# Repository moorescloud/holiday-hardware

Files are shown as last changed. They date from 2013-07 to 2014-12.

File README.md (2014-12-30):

MooresCloud Holiday Hardware
==============

The Holiday controller is an open source hardware design, originally inspired by the [Olimex OlinuXino] (https://www.olimex.com/Products/OLinuXino/iMX233/) - a Freescale iMX233 based embedded linux development board.

We used the OlinuXino iMX233 Maxi and Micro boards during development and testing of both the Light and Holiday, before designing our own custom PCB layout to suit the form factor and specific requirements.  The Holiday also incorporates an ATmega328 (running the "Arduino" environment) that communicates with the Linux environment for handling control during Linux boot-up and providing the tight timing requirements of sending data to the WS2812 LEDs.

These designs are in Altium Designer (v13) format, and the Altium files along with the BOM, PDF, and gerber outputs are now available under the [Creative Commons Attribution Share-Alike license] (http://creativecommons.org/licenses/by-sa/2.0/au/)

Controller r2a changes crystal Y2 from 16MHz to 20MHz
- this is the version that shipped in 2013/2014, with ECO001 applied

Controller r3 incorporated ECO001 changes and some other minor improvements noted in the schematics, and should be used with Globe r4 for signal integrity and EMC

The MooresGlobe used by Holiday went through several revision for prototyping and DFM review.

Globe r2b uses the WorldSemi WS2812 (6 pin 5050 footprint)
- this is the version that shipped in 2013/2014, with ECO002 applied

Globe r3 incorporated ECO002 and some other minor improvements

Globe r4 incorporated further improvements following discussions with WorldSemi and additional signal integrity and EMC measurements. This revision uses the newer WS2812B (4 pin 5050 footprint)

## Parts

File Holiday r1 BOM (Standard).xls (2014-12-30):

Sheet: Part List Report
 | Component list |  | Bill of Materials For Variant [Standard] of Project [Holiday r1.PrjPcb] (No PCB Document Selected)
 | Source Data From: |  | Holiday r1.PrjPcb |  |  | Report Date: | 7/05/2013 |  |  | 12:21:27 PM
 | Project: |  | Holiday r1.PrjPcb |  |  | Print Date: | 2013-05-17 |  |  | 21:22:57
 | Variant: |  | Standard
# | Designator | Description | Comment | 1.Manufacturer | 2.MfgNo | 3.Supplier | 4.CatNo | Quantity | 9.UnitCost | Total
1 | C1, C2, C3, C4, C5, C6, C8, C9, C10, C11, C13, C14, C16, C18, C19, C20, C39, C40, C45, C52, C53 | Capacitor | 22u | TDK | C1608X5R0J226M080AC | Digikey | 445-8028-1-ND | 21 | 0.0816 | $1.7136
2 | C7, C12, C15, C17, C22, C23, C24, C25, C26, C27, C28, C29, C31, C32, C34, C36, C38, C41, C44, C46, C47, C48, C56, C57 | Capacitor | 100n | Yageo | CC0603ZRY5V9BB104 | Digikey | 311-1343-2-ND | 24 | 0.0034 | $0.0816
3 | C30 | Capacitor | 10p | Murata | GRM1885C1H100JA01D | Digikey | 490-1403-1-ND | 1 | 0.008 | $0.0080
4 | C33, C35, C42, C43 | Capacitor | 18p | Murata | GRM1885C1H180JA01D | Digikey | 490-1409-2-ND | 4 | 0.008 | $0.0320
5 | C37 | Capacitor | 1u | Yageo | CC0603ZRY5V7BB105 | Digikey | 311-1372-2-ND | 1 | 0.0083 | $0.0083
6 | C50, C51 | Polarized Capacitor (Surface Mount) | 100uF, 10V, Tant | AVX | TPSD107K010R0100 | Digikey | 478-1777-2-ND | 2 | 0.33 | $0.6600
7 | D2, D3, D4, D5, D6 | Schottky Diode | BAT54 | Fairchild | BAT54 | Digikey | BAT54FSTR-ND | 5 | 0.027 | $0.1350
8 | J1 | microSD Socket Push/Pull | microSD | Molex | 473093751 | Digikey | WM3974TR-ND | 1 | 0.90 | $0.9000
9 | J6 | DC JACK | DC JACK | CUI Inc | PJ-002AH-SMT-TR | Digikey | CP-002AHPJTR-ND | 1 | 0.6554 | $0.6554
10 | J7 | USB A Female | USB A Female | Assmann | AU-Y1006-R | Digikey | AE9924-ND | 1 | 0.430 | $0.4300
11 | J8 | Connector | JST S3B-EH | JST | S3B-EH(LF)(SN) | Digikey | 455-1626-ND | 1 | 0.07216 | $0.0722
12 | L1 | Inductor | 22uH 1.5A | Taiyo Yuden | NR6045T220M | Digikey | 587-2082-1-ND | 1 | 0.12 | $0.1200
13 | L2 | Ferrite | 470nH | Abracon | AISC-0805-R47J-T | Digikey | 535-10509-1-ND | 1 | 0.10 | $0.1000
14 | L3 | Ferrite | 600R 1.5A | Laird | MI0805K601R-10 | DigiKey | 240-2390-2-ND | 1 | 0.025 | $0.0250
15 | L4, L6 | Ferrite | 750R 200mA | Laird | HZ0603B751R-10 | DigiKey | 240-2547-2-ND | 2 | 0.0165 | $0.0330
16 | L5, L7 | Ferrite | 120R 3.5A | Laird | HI0805O121R-10 | DigiKey | 240-2393-2-ND | 2 | 0.0234 | $0.0468
17 | Q1, Q2, Q3, Q4 | Dual N Channel MOSFET | BSS138PS | NXP | BSS138PS,115 | Digikey | 568-8393-2-ND | 4 | 0.07 | $0.2800
18 | R2, R12 | Resistor | 10k | Yageo | RC0603FR-0710KL | Digikey | 311-10.0KHRTR-ND | 2 | 0.0017 | $0.0034
19 | R4, R5, R6, R8 | Resistor | 1k | Yageo | RC0603FR-071KL | Digikey | 311-1.00KHRTR-ND | 4 | 0.0017 | $0.0068
20 | R7 | Resistor | 100k | Yageo | RC0603FR-07100KL | Digikey | 311-100KHRTR-ND | 1 | 0.0017 | $0.0017
21 | R9 | Resistor | 0R | Yageo | RC0603JR-070RL | Digikey | 311-0.0GRTR-ND | 1 | 0.00131 | $0.0013
22 | RP1 | Resistor Pack 4x0603 | 100k | Vishay Dale | CRA06S083100KJTA | Digikey | CRA6S8100KTR-ND | 1 | 0.009 | $0.0090
23 | RP2, RP3, RP4, RP5, RP6, RP7, RP8 | Resistor Pack 4x0603 | 10k | Vishay Dale | CRA06S08310K0JTA | Digikey | CRA6S810KTR-ND | 7 | 0.009 | $0.0630
24 | SW1, SW2, SW3 | Pushbutton SMT | TACTILE_SWITCH | TE Connectivity | FSM4JSMATR | Digikey | 450-1759-2-ND | 3 | 0.1543 | $0.4629
25 | U1 | Freescale i.MX233 128 pin LQFP package | MCIMX233DAG4B | Freescale | MCIMX233DAG4C | Digikey | MCIMX233DAG4C-ND | 1 | 4.880 | $4.8800
26 | U2 | SDRAM DDR400 66TSOP-II | H5DU5162ETR-E3C | Hynix | H5DU5162ETR-E3C |  |  | 1 | 2.240 | $2.2400
27 | U3 | ATMEGA328 - TQFP | ATMEGA328 | Atmel | ATMEGA328-AUR | Digikey | ATMEGA328-AURTR-ND | 1 | 1.608 | $1.6080
28 | U4, U5 | CMOS Logic Level Shifter | MC74VHC1GT50 | On Semi | M74VHC1GT50DTT1G | Digikey | M74VHC1GT50DTT1GOSTR-ND | 2 | 0.07 | $0.1400
29 | U6 | CAT24C64W EEPROM I2C | 8kB EEPROM | On Semi | CAT24C64WI-GT3 | Digikey | CAT24C64WI-GT3TR-ND | 1 | 0.148 | $0.1480
30 | Y1 | ABMM2 SMD Crystal | 24Mhz | Abracon | ABMM2-24.000MHZ-E2-T | Digikey | 535-9638-2-ND | 1 | 0.48 | $0.4800
31 | Y2 | ABMM2 SMD Crystal | 16MHz | Abracon | ABMM2-16.000MHZ-E2-T | Digikey | 535-9634-2-ND | 1 | 0.48 | $0.4800
32 | Z1 | SMBJ Unidirectional TVS | SMBJ TVS | Bourns | SMBJ6.0A | Digikey | SMBJ6.0ABTR-ND | 1 | 0.10 | $0.1000
33 | Z2, Z3, Z4 | Two-Line ESD-Protection in SOT23 | GSOT05C | Vishay Semi | GSOT05C-GS08 | Digikey | 751-1415-2-ND | 3 | 0.085 | $0.2550
Approved |  |  |  | Notes |  |  |  | 104 |  | $16.1800

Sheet: Project Information
Project Full Path | \\PIXEL\Users\Kean\My Documents\Kean Electronics\MooresCloud\PCB\Holiday r1\Holiday r1.PrjPcb
Project Filename | Holiday r1.PrjPcb
Variant Name | Standard
Data-Source Filename | Holiday r1.PrjPcb
Data-Source Full Path | \\PIXEL\Users\Kean\My Documents\Kean Electronics\MooresCloud\PCB\Holiday r1\Holiday r1.PrjPcb
Title | Bill of Materials For Variant [Standard] of Project [Holiday r1.PrjPcb] (No PCB Document Selected)
Total Quantity | 104
Report Time | 12:21:27 PM
Report Date | 7/05/2013
Report Date & Tine | 7/05/2013 12:21:27 PM
Output Name | Bill of Materials
Output Type | BOM_PartType
Output Generator Name | BOM
Output Generator Description | Bill of Materials

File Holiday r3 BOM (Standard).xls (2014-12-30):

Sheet: Part List Report
 | Component list |  | Bill of Materials For Variant [Standard] of Project [Holiday r3.PrjPcb] (No PCB Document Selected)
 | Source Data From: |  | Holiday r3.PrjPcb |  |  | Report Date: | 14/02/2014 |  |  | 4:12:48 PM
 | Project: |  | Holiday r3.PrjPcb |  |  | Print Date: | 2014-02-25 |  |  | 22:38:11
 | Variant: |  | Standard
# | Designator | Description | Comment | 1.Manufacturer | 2.MfgNo | 3.Supplier | 4.CatNo | Quantity | 9.UnitCost | Total
1 | C1, C2, C3, C4, C5, C6, C8, C9, C11, C13, C14, C16, C18, C19, C20, C39, C40 | Capacitor | 22u | TDK | C1608X5R0J226M080AC | Digikey | 445-8028-1-ND | 17 | 0.0816 | $1.3872
2 | C7, C12, C15, C17, C22, C23, C24, C25, C26, C27, C28, C29, C31, C32, C34, C36, C38, C41, C44, C46, C47, C48, C56, C57 | Capacitor | 100n | Yageo | CC0603ZRY5V9BB104 | Digikey | 311-1343-2-ND | 24 | 0.0034 | $0.0816
3 | C10, C45, C52, C53, C62, C63 | Capacitor | 22u 10V | TDK | C1608X5R1A226M080AC | Digikey | 445-9077-2-ND | 6 | 0.10500 | $0.6300
4 | C30 | Capacitor | 10p | Murata | GRM1885C1H100JA01D | Digikey | 490-1403-1-ND | 1 | 0.008 | $0.0080
5 | C33, C35, C42, C43 | Capacitor | 18p | Murata | GRM1885C1H180JA01D | Digikey | 490-1409-2-ND | 4 | 0.008 | $0.0320
6 | C37 | Capacitor | 1u | Yageo | CC0603ZRY5V7BB105 | Digikey | 311-1372-2-ND | 1 | 0.0083 | $0.0083
7 | C50, C51 | Polarized Capacitor (Surface Mount) | 100uF, 10V, Tant | AVX | TPSD107K010R0100 | Digikey | 478-1777-2-ND | 2 | 0.33 | $0.6600
8 | C54 | Capacitor | 470p | Yageo | CC0603JRNPO9BN471 | Digikey | 311-1520-2-ND | 1 | 0.00637 | $0.0064
9 | C61 | Capacitor | 1u | Taiyo Yuden | UMK212B7105KG-T | Digikey | 587-2910-2-ND | 1 | 0.03079 | $0.0308
10 | D2, D3, D4, D5 | Schottky Diode | BAT54 | Fairchild | BAT54 | Digikey | BAT54FSTR-ND | 4 | 0.027 | $0.1080
11 | J1 | microSD Socket Push/Pull | microSD | Molex | 473093751 | Digikey | WM3974TR-ND | 1 | 0.90 | $0.9000
12 | J6 | DC JACK | DC JACK | CUI Inc | PJ-002AH-SMT-TR | Digikey | CP-002AHPJTR-ND | 1 | 0.6554 | $0.6554
13 | J7 | USB A Female | USB A Female | Assmann | AU-Y1006-R | Digikey | AE9924-ND | 1 | 0.430 | $0.4300
14 | J8 | Connector | JST S3B-EH | JST | S3B-EH(LF)(SN) | Digikey | 455-1626-ND | 1 | 0.07216 | $0.0722
15 | L1 | Inductor | 22uH 1.5A | Taiyo Yuden | NR6045T220M | Digikey | 587-2082-1-ND | 1 | 0.12 | $0.1200
16 | L2 | Ferrite | 470nH | Abracon | AISC-0805-R47J-T | Digikey | 535-10509-1-ND | 1 | 0.10 | $0.1000
17 | L3, L8 | Ferrite | 600R 1.5A | Laird | MI0805K601R-10 | DigiKey | 240-2390-2-ND | 2 | 0.025 | $0.0500
18 | L4 | Ferrite | 750R 200mA | Laird | HZ0603B751R-10 | DigiKey | 240-2547-2-ND | 1 | 0.0165 | $0.0165
19 | L5, L7 | Ferrite | 120R 3.5A | Laird | HI0805O121R-10 | DigiKey | 240-2393-2-ND | 2 | 0.0234 | $0.0468
20 | Q1, Q2, Q3, Q4 | Dual N Channel MOSFET | BSS138PS | NXP | BSS138PS,115 | Digikey | 568-8393-2-ND | 4 | 0.07 | $0.2800
21 | R2, R12, R16 | Resistor | 10k | Yageo | RC0603FR-0710KL | Digikey | 311-10.0KHRTR-ND | 3 | 0.0017 | $0.0051
22 | R3 | Resistor | 120R | Yageo | RC0603FR-07120RL | Digikey | 311-120HRTR-ND | 1 | 0.0017 | $0.0017
23 | R4, R5, R6, R8, R13, R14 | Resistor | 1k | Yageo | RC0603FR-071KL | Digikey | 311-1.00KHRTR-ND | 6 | 0.0017 | $0.0102
24 | R7, R17 | Resistor | 100k | Yageo | RC0603FR-07100KL | Digikey | 311-100KHRTR-ND | 2 | 0.0017 | $0.0034
25 | R9 | Resistor | 0R | Yageo | RC0603JR-070RL | Digikey | 311-0.0GRTR-ND | 1 | 0.00131 | $0.0013
26 | R18 | Resistor | 75R | Yageo | RC0603FR-0775RL | DigiKey | 311-75.0HRTR-ND | 1 | 0.00171 | $0.0017
27 | RP1 | Resistor Pack 4x0603 | 100k | Vishay Dale | CRA06S083100KJTA | Digikey | CRA6S8100KTR-ND | 1 | 0.009 | $0.0090
28 | RP2, RP3, RP4, RP5, RP6 | Resistor Pack 4x0603 | 10k | Vishay Dale | CRA06S08310K0JTA | Digikey | CRA6S810KTR-ND | 5 | 0.009 | $0.0450
29 | RP7, RP8 | Resistor Pack 4x0603 | 4k7 | Vishay Dale | CRA06S0834K70JTA | Digikey | CRA6S84.7KTR-ND | 2 | 0.009 | $0.0180
30 | SW1, SW2, SW3 | Pushbutton SMT | TACTILE_SWITCH | TE Connectivity | FSM4JSMATR | Digikey | 450-1759-2-ND | 3 | 0.1543 | $0.4629
31 | U1 | Freescale i.MX233 128 pin LQFP package | MCIMX233DAG4B | Freescale | MCIMX233DAG4C | Digikey | MCIMX233DAG4C-ND | 1 | 4.880 | $4.8800
32 | U2 | SDRAM DDR400 66TSOP-II | H5DU5162ETR-E3C | Hynix | H5DU5162ETR-E3C |  |  | 1 | 2.240 | $2.2400
33 | U3 | ATMEGA328 - TQFP | ATMEGA328 | Atmel | ATMEGA328-AUR | Digikey | ATMEGA328-AURTR-ND | 1 | 1.608 | $1.6080
34 | U4, U5 | CMOS Logic Level Shifter | MC74VHC1GT50 | On Semi | M74VHC1GT50DTT1G | Digikey | M74VHC1GT50DTT1GOSTR-ND | 2 | 0.07 | $0.1400
35 | U6 | CAT24C64W EEPROM I2C | 8kB EEPROM | On Semi | CAT24C64WI-GT3 | Digikey | CAT24C64WI-GT3TR-ND | 1 | 0.148 | $0.1480
36 | Y1 | ABMM2 SMD Crystal | 24Mhz | Abracon | ABMM2-24.000MHZ-E2-T | Digikey | 535-9638-2-ND | 1 | 0.48 | $0.4800
37 | Y2 | ABMM2 SMD Crystal | 20MHz | Abracon | ABMM2-20.000MHZ-E2-T | Digikey | 535-9637-2-ND | 1 | 0.48 | $0.4800
38 | Z1 | SMBJ Unidirectional TVS | SMBJ TVS | Bourns | SMBJ6.0A | Digikey | SMBJ6.0ABTR-ND | 1 | 0.10 | $0.1000
39 | Z2, Z3, Z4 | Two-Line ESD-Protection in SOT23 | GSOT05C | Vishay Semi | GSOT05C-GS08 | Digikey | 751-1415-2-ND | 3 | 0.085 | $0.2550
Approved |  |  |  | Notes |  |  |  | 113 |  | $16.5124

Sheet: Project Information
Project Full Path | \\PIXEL\Users\Kean\My Documents\Kean Electronics\MooresCloud\PCB\Holiday r3\Holiday r3.PrjPcb
Project Filename | Holiday r3.PrjPcb
Variant Name | Standard
Data-Source Filename | Holiday r3.PrjPcb
Data-Source Full Path | \\PIXEL\Users\Kean\My Documents\Kean Electronics\MooresCloud\PCB\Holiday r3\Holiday r3.PrjPcb
Title | Bill of Materials For Variant [Standard] of Project [Holiday r3.PrjPcb] (No PCB Document Selected)
Total Quantity | 113
Report Time | 4:12:48 PM
Report Date | 14/02/2014
Report Date & Tine | 14/02/2014 4:12:48 PM
Output Name | Bill of Materials
Output Type | BOM_PartType
Output Generator Name | BOM
Output Generator Description | Bill of Materials

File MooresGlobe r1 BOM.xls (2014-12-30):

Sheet: Part List Report
 | Component list |  | Bill of Materials For Schematic Document [MooresGlobe r1.SchDoc]
 | Source Data From: |  | MooresGlobe r1.SchDoc |  |  | Report Date: | 3/05/2013 |  |  | 10:07:53 PM
 | Project: |  | MooresGlobe r1.PrjPcb |  |  | Print Date: | 2013-05-03 |  |  | 22:07:57
 | Variant: |  | None
# | Designator | Description | Footprint | 1.Manufacturer | 2.MfgNo | 3.Supplier | 4.CatNo | Quantity | 9.UnitCost | Total
1 | C1 | Capacitor Ceramic 100n 50V Y5V 0603 | ARA_0603 | Yageo | CC0603ZRY5V9BB104 | DigiKey | 311-1343-2-ND | 1 | 0.00206 | $0.0021
2 | LED1 | WorldSemi WS2812 Smart RGB LED | PLCC6-IPC | WorldSemi | WS2812 | Shenzhen Scott Electronics | sc-WS2811-5050 | 1 | 0.15 | $0.1500
3 | R1 | Resistor 100R 0.1W 5% 0603 | ARA_0603 | Yageo | RC0603JR-07100RL | DigiKey | 311-100GRTR-ND | 1 | 0.00092 | $0.0009
Approved |  |  |  | Notes |  |  |  | 3 |  | $0.1530

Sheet: Project Information
Project Full Path | \\PIXEL\Users\Kean\My Documents\Kean Electronics\MooresCloud\PCB\Globe r1\MooresGlobe r1.PrjPcb
Project Filename | MooresGlobe r1.PrjPcb
Variant Name | None
Data-Source Filename | MooresGlobe r1.SchDoc
Data-Source Full Path | \\PIXEL\Users\Kean\My Documents\Kean Electronics\MooresCloud\PCB\Globe r1\MooresGlobe r1.SchDoc
Title | Bill of Materials For Schematic Document [MooresGlobe r1.SchDoc]
Total Quantity | 3
Report Time | 10:07:53 PM
Report Date | 3/05/2013
Report Date & Tine | 3/05/2013 10:07:53 PM
Output Name | Bill of Materials
Output Type | BOM_PartType
Output Generator Name | BOM
Output Generator Description | Bill of Materials

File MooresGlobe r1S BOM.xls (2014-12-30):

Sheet: Part List Report
 | Component list |  | Bill of Materials For Schematic Document [MooresGlobe r1S.SchDoc]
 | Source Data From: |  | MooresGlobe r1S.SchDoc |  |  | Report Date: | 11/06/2013 |  |  | 8:02:30 PM
 | Project: |  | MooresGlobe r1S.PrjPcb |  |  | Print Date: | 2013-06-11 |  |  | 20:02:38
 | Variant: |  | None
# | Designator | Description | Comment | 1.Manufacturer | 2.MfgNo | 3.Supplier | 4.CatNo | Quantity | 9.UnitCost | Total
1 | C1 | Capacitor Ceramic 100n 50V Y5V 0603 | 100n | Yageo | CC0603ZRY5V9BB104 | DigiKey | 311-1343-2-ND | 1 | 0.00206 | $0.0021
2 | LED1 | WorldSemi WS2812 Smart RGB LED | WS2812 | WorldSemi | WS2812 | Shenzhen Scott Electronics | sc-WS2811-5050 | 1 | 0.15 | $0.1500
3 | R1 | Resistor 100R 0.1W 5% 0603 | 100R | Yageo | RC0603JR-07100RL | DigiKey | 311-100GRTR-ND | 1 | 0.00092 | $0.0009
Approved |  |  |  | Notes |  |  |  | 3 |  | $0.1530

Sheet: Project Information
Project Full Path | \\PIXEL\Users\Kean\My Documents\Kean Electronics\MooresCloud\PCB\Globe r1S\MooresGlobe r1S.PrjPcb
Project Filename | MooresGlobe r1S.PrjPcb
Variant Name | None
Data-Source Filename | MooresGlobe r1S.SchDoc
Data-Source Full Path | \\PIXEL\Users\Kean\My Documents\Kean Electronics\MooresCloud\PCB\Globe r1S\MooresGlobe r1S.SchDoc
Title | Bill of Materials For Schematic Document [MooresGlobe r1S.SchDoc]
Total Quantity | 3
Report Time | 8:02:30 PM
Report Date | 11/06/2013
Report Date & Tine | 11/06/2013 8:02:30 PM
Output Name | Bill of Materials
Output Type | BOM_PartType
Output Generator Name | BOM
Output Generator Description | Bill of Materials

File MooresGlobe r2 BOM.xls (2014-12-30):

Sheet: Part List Report
 | Component list |  | Bill of Materials For Schematic Document [MooresGlobe r2.SchDoc]
 | Source Data From: |  | MooresGlobe r2.SchDoc |  |  | Report Date: | 9/07/2013 |  |  | 12:20:01 PM
 | Project: |  | MooresGlobe r2.PrjPcb |  |  | Print Date: | 2013-07-09 |  |  | 12:20:08
 | Variant: |  | None
# | Designator | Description | Comment | 1.Manufacturer | 2.MfgNo | 3.Supplier | 4.CatNo | Quantity | 9.UnitCost | Total
1 | C1 | Capacitor Ceramic 100n 50V Y5V 0603 | 100n | Yageo | CC0603ZRY5V9BB104 | DigiKey | 311-1343-2-ND | 1 | 0.00206 | $0.0021
2 | LED1 | WorldSemi WS2812 Smart RGB LED | WS2812 | WorldSemi | WS2812 | Shenzhen Scott Electronics | sc-WS2811-5050 | 1 | 0.15 | $0.1500
3 | R1 | Resistor 100R 0.1W 5% 0603 | 100R | Yageo | RC0603JR-07100RL | DigiKey | 311-100GRTR-ND | 1 | 0.00092 | $0.0009
Approved |  |  |  | Notes |  |  |  | 3 |  | $0.1530

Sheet: Project Information
Project Full Path | \\PIXEL\Users\Kean\My Documents\Kean Electronics\MooresCloud\PCB\Globe r2\MooresGlobe r2.PrjPcb
Project Filename | MooresGlobe r2.PrjPcb
Variant Name | None
Data-Source Filename | MooresGlobe r2.SchDoc
Data-Source Full Path | \\PIXEL\Users\Kean\My Documents\Kean Electronics\MooresCloud\PCB\Globe r2\MooresGlobe r2.SchDoc
Title | Bill of Materials For Schematic Document [MooresGlobe r2.SchDoc]
Total Quantity | 3
Report Time | 12:20:01 PM
Report Date | 9/07/2013
Report Date & Tine | 9/07/2013 12:20:01 PM
Output Name | Bill of Materials
Output Type | BOM_PartType
Output Generator Name | BOM
Output Generator Description | Bill of Materials

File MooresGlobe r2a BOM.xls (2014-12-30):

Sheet: Part List Report
 | Component list |  | Bill of Materials For Schematic Document [MooresGlobe r2a.SchDoc]
 | Source Data From: |  | MooresGlobe r2a.SchDoc |  |  | Report Date: | 12/07/2013 |  |  | 3:11:09 PM
 | Project: |  | MooresGlobe r2a.PrjPcb |  |  | Print Date: | 2013-07-12 |  |  | 15:11:15
 | Variant: |  | None
# | Designator | Description | Comment | 1.Manufacturer | 2.MfgNo | 3.Supplier | 4.CatNo | Quantity | 9.UnitCost | Total
1 | C1 | Capacitor Ceramic 100n 50V Y5V 0603 | 100n | Yageo | CC0603ZRY5V9BB104 | DigiKey | 311-1343-2-ND | 1 | 0.00206 | $0.0021
2 | LED1 | WorldSemi WS2812 Smart RGB LED | WS2812 | WorldSemi | WS2812 | Shenzhen Scott Electronics | sc-WS2811-5050 | 1 | 0.15 | $0.1500
3 | R1 | Resistor 100R 0.1W 5% 0603 | 100R | Yageo | RC0603JR-07100RL | DigiKey | 311-100GRTR-ND | 1 | 0.00092 | $0.0009
Approved |  |  |  | Notes |  |  |  | 3 |  | $0.1530

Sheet: Project Information
Project Full Path | \\PIXEL\Users\Kean\My Documents\Kean Electronics\MooresCloud\PCB\Globe r2a\MooresGlobe r2a.PrjPcb
Project Filename | MooresGlobe r2a.PrjPcb
Variant Name | None
Data-Source Filename | MooresGlobe r2a.SchDoc
Data-Source Full Path | \\PIXEL\Users\Kean\My Documents\Kean Electronics\MooresCloud\PCB\Globe r2a\MooresGlobe r2a.SchDoc
Title | Bill of Materials For Schematic Document [MooresGlobe r2a.SchDoc]
Total Quantity | 3
Report Time | 3:11:09 PM
Report Date | 12/07/2013
Report Date & Tine | 12/07/2013 3:11:09 PM
Output Name | Bill of Materials
Output Type | BOM_PartType
Output Generator Name | BOM
Output Generator Description | Bill of Materials

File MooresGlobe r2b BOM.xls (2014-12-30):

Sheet: Part List Report
 | Component list |  | Bill of Materials For Schematic Document [MooresGlobe r2b.SchDoc]
 | Source Data From: |  | MooresGlobe r2b.SchDoc |  |  | Report Date: | 20/08/2013 |  |  | 11:01:06 AM
 | Project: |  | MooresGlobe r2b.PrjPcb |  |  | Print Date: | 2013-08-20 |  |  | 11:01:14
 | Variant: |  | None
# | Designator | Description | Comment | 1.Manufacturer | 2.MfgNo | 3.Supplier | 4.CatNo | Quantity | 9.UnitCost | Total
1 | C1 | Capacitor Ceramic 100n 50V Y5V 0603 | 100n | Yageo | CC0603ZRY5V9BB104 | DigiKey | 311-1343-2-ND | 1 | 0.00206 | $0.0021
2 | LED1 | WorldSemi WS2812 Smart RGB LED | WS2812 | WorldSemi | WS2812 | Shenzhen Worldsemi Technology | WS2812 | 1 | 0.15 | $0.1500
3 | R1 | Resistor 100R 0.1W 5% 0603 | 100R | Yageo | RC0603JR-07100RL | DigiKey | 311-100GRTR-ND | 1 | 0.00092 | $0.0009
Approved |  |  |  | Notes |  |  |  | 3 |  | $0.1530

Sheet: Project Information
Project Full Path | \\PIXEL\Users\Kean\My Documents\Kean Electronics\MooresCloud\PCB\Globe r2b\MooresGlobe r2b.PrjPcb
Project Filename | MooresGlobe r2b.PrjPcb
Variant Name | None
Data-Source Filename | MooresGlobe r2b.SchDoc
Data-Source Full Path | \\PIXEL\Users\Kean\My Documents\Kean Electronics\MooresCloud\PCB\Globe r2b\MooresGlobe r2b.SchDoc
Title | Bill of Materials For Schematic Document [MooresGlobe r2b.SchDoc]
Total Quantity | 3
Report Time | 11:01:06 AM
Report Date | 20/08/2013
Report Date & Tine | 20/08/2013 11:01:06 AM
Output Name | Bill of Materials
Output Type | BOM_PartType
Output Generator Name | BOM
Output Generator Description | Bill of Materials

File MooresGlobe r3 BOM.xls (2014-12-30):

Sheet: Part List Report
 | Component list |  | Bill of Materials For Schematic Document [MooresGlobe r3.SchDoc]
 | Source Data From: |  | MooresGlobe r3.SchDoc |  |  | Report Date: | 12/11/2013 |  |  | 3:54:06 PM
 | Project: |  | MooresGlobe r3.PrjPcb |  |  | Print Date: | 2013-11-12 |  |  | 15:54:08
 | Variant: |  | None
# | Designator | Description | Comment | 1.Manufacturer | 2.MfgNo | 3.Supplier | 4.CatNo | Quantity | 9.UnitCost | Total
1 | C1 | Capacitor Ceramic 100n 50V Y5V 0603 | 100n | Yageo | CC0603ZRY5V9BB104 | DigiKey | 311-1343-2-ND | 1 | 0.00206 | $0.0021
2 | C2 | Capacitor Ceramic 470p 50V NPO 0603 | 470p | Yageo | CC0603JRNPO9BN471 | DigiKey | 311-1520-2-ND | 1 | 0.00526 | $0.0053
3 | LED1 | WorldSemi WS2812 Smart RGB LED | WS2812 | WorldSemi | WS2812 | Shenzhen Worldsemi Technology | WS2812 | 1 | 0.15 | $0.1500
4 | R1 | Resistor 100R 0.1W 5% 0603 | 100R | Yageo | RC0603JR-07100RL | DigiKey | 311-100GRTR-ND | 1 | 0.00092 | $0.0009
5 | R2 | Resistor 100R 0.1W 5% 0603 | 0R | Yageo | RC0603JR-070RL | DigiKey | 311-0.0GRTR-ND | 1 | 0.00092 | $0.0009
Approved |  |  |  | Notes |  |  |  | 5 |  | $0.1592

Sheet: Project Information
Project Full Path | \\PIXEL\Users\Kean\My Documents\Kean Electronics\MooresCloud\PCB\Globe r3\MooresGlobe r3.PrjPcb
Project Filename | MooresGlobe r3.PrjPcb
Variant Name | None
Data-Source Filename | MooresGlobe r3.SchDoc
Data-Source Full Path | \\PIXEL\Users\Kean\My Documents\Kean Electronics\MooresCloud\PCB\Globe r3\MooresGlobe r3.SchDoc
Title | Bill of Materials For Schematic Document [MooresGlobe r3.SchDoc]
Total Quantity | 5
Report Time | 3:54:06 PM
Report Date | 12/11/2013
Report Date & Tine | 12/11/2013 3:54:06 PM
Output Name | Bill of Materials
Output Type | BOM_PartType
Output Generator Name | BOM
Output Generator Description | Bill of Materials

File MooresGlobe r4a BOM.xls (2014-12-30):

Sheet: Part List Report
 | Component list |  | Bill of Materials For Schematic Document [MooresGlobe r4a.SchDoc]
 | Source Data From: |  | MooresGlobe r4a.SchDoc |  |  | Report Date: | 21/02/2014 |  |  | 11:58:54 AM
 | Project: |  | MooresGlobe r4a.PrjPcb |  |  | Print Date: | 2014-02-21 |  |  | 12:09:30
 | Variant: |  | None
# | Designator | Description | Comment | 1.Manufacturer | 2.MfgNo | 3.Supplier | 4.CatNo | Quantity | 9.UnitCost | Total
1 | C1 | Capacitor Ceramic 100n 50V Y5V 0603 | 100n | Yageo | CC0603ZRY5V9BB104 | DigiKey | 311-1343-2-ND | 1 |  | $0.0000
2 | C2 | Capacitor Ceramic 220p 50V NPO 0603 | 220p | Samsung | CL10C221JB8NNNC | DigiKey | 1276-1048-2-ND | 1 |  | $0.0000
3 | LED1 | WorldSemi WS2812B Smart RGB LED | WS2812B | WorldSemi | WS2812B | WorldSemi | WS2812B | 1 |  | $0.0000
4 | R1 | Resistor 330R 0.1W 5% 0603 | 330R | Yageo | RC0603JR-07330RL | DigiKey | 311-330GRTR-ND | 1 |  | $0.0000
5 | R2 | Resistor 75R 0.1W 5% 0603 | 75R | Yageo | RC0603JR-0775RL | DigiKey | 311-75GRTR-ND | 1 |  | $0.0000
Approved |  |  |  | Notes |  |  |  | 5 |  | $0.0000

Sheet: Project Information
Project Full Path | \\PIXEL\Users\Kean\My Documents\Kean Electronics\MooresCloud\PCB\Globe r4a\MooresGlobe r4a.PrjPcb
Project Filename | MooresGlobe r4a.PrjPcb
Variant Name | None
Data-Source Filename | MooresGlobe r4a.SchDoc
Data-Source Full Path | \\PIXEL\Users\Kean\My Documents\Kean Electronics\MooresCloud\PCB\Globe r4a\MooresGlobe r4a.SchDoc
Title | Bill of Materials For Schematic Document [MooresGlobe r4a.SchDoc]
Total Quantity | 5
Report Time | 11:58:54 AM
Report Date | 21/02/2014
Report Date & Tine | 21/02/2014 11:58:54 AM
Output Name | Bill of Materials
Output Type | BOM_PartType
Output Generator Name | BOM
Output Generator Description | Bill of Materials

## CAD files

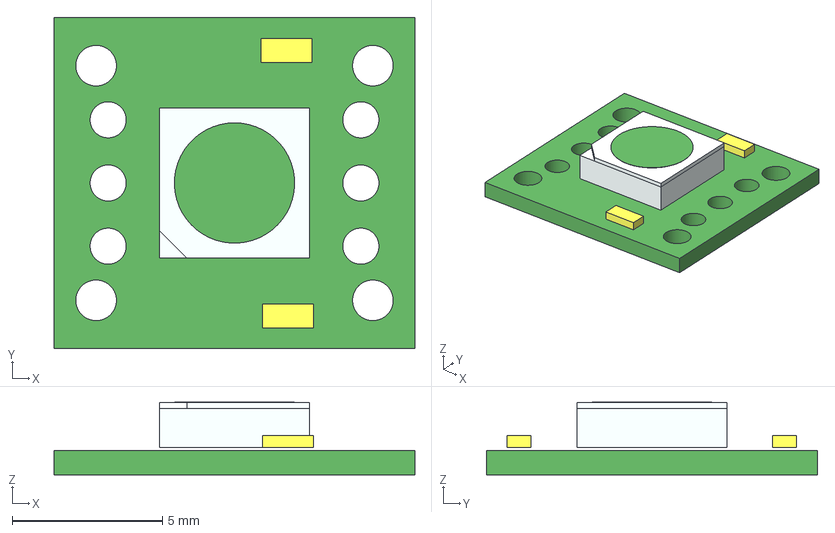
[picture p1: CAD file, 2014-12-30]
MooresGlobe r2a.step
12.0 x 11.0 x 2.41 mm
Board
Extruded x 4

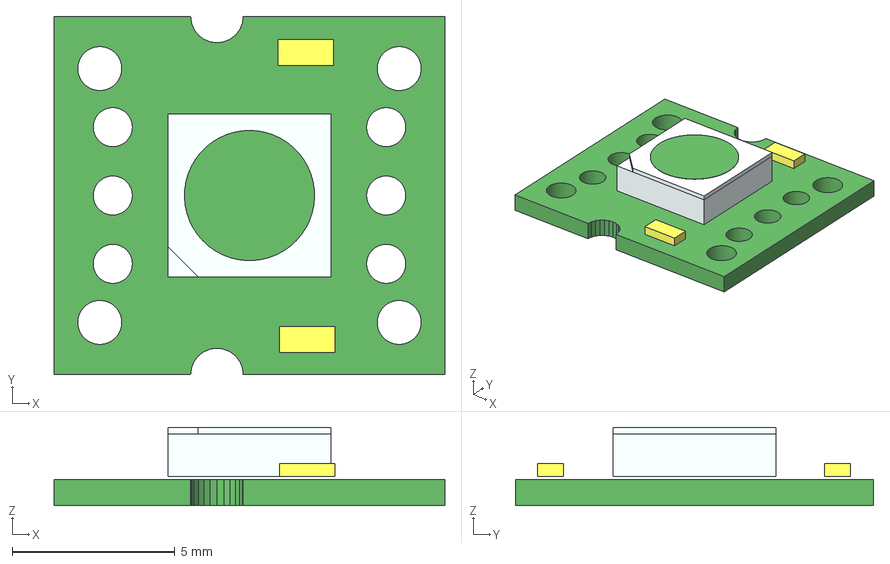
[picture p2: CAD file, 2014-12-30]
MooresGlobe r2.step
12.0 x 11.0 x 2.41 mm
Board
Extruded x 4

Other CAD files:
MooresGlobe r1.step

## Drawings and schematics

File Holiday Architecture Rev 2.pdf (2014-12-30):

# MOORESCLOUD HOLIDAY HARDWARE ARCHITECTURE

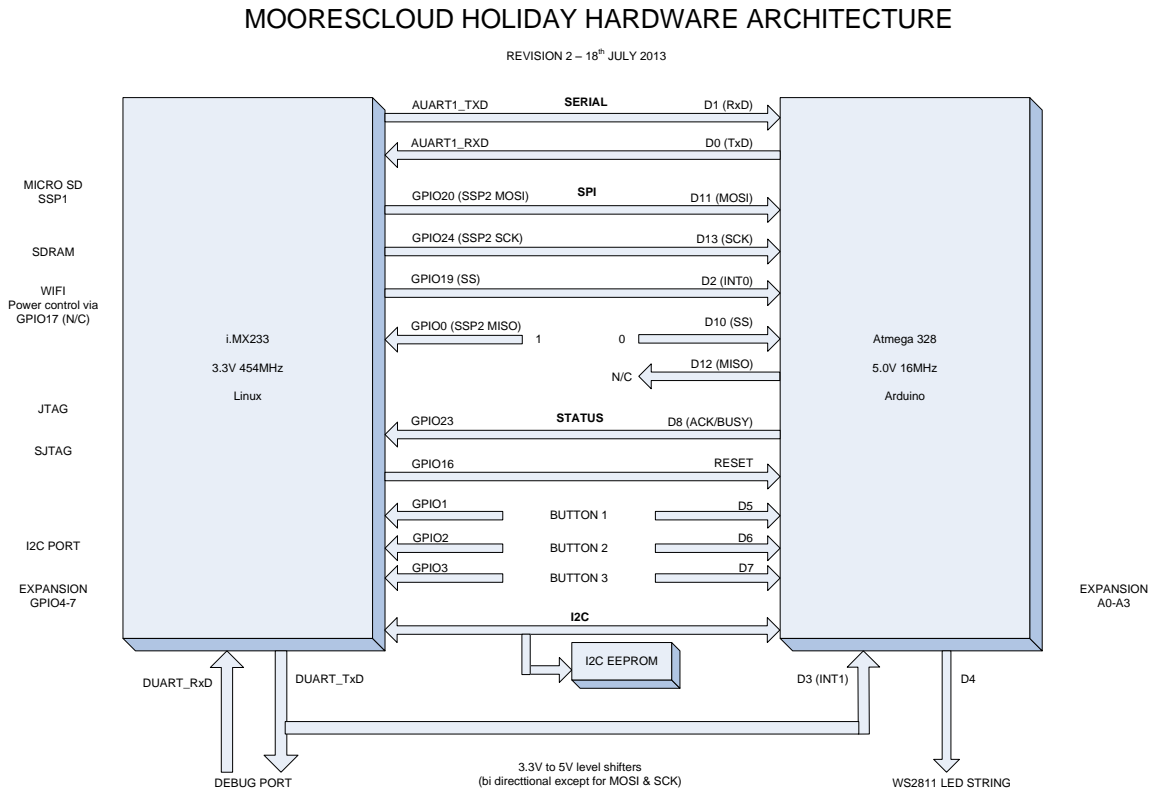
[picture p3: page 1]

3.3V to 5V level shifters (bi directtional except for MOSI & SCK)

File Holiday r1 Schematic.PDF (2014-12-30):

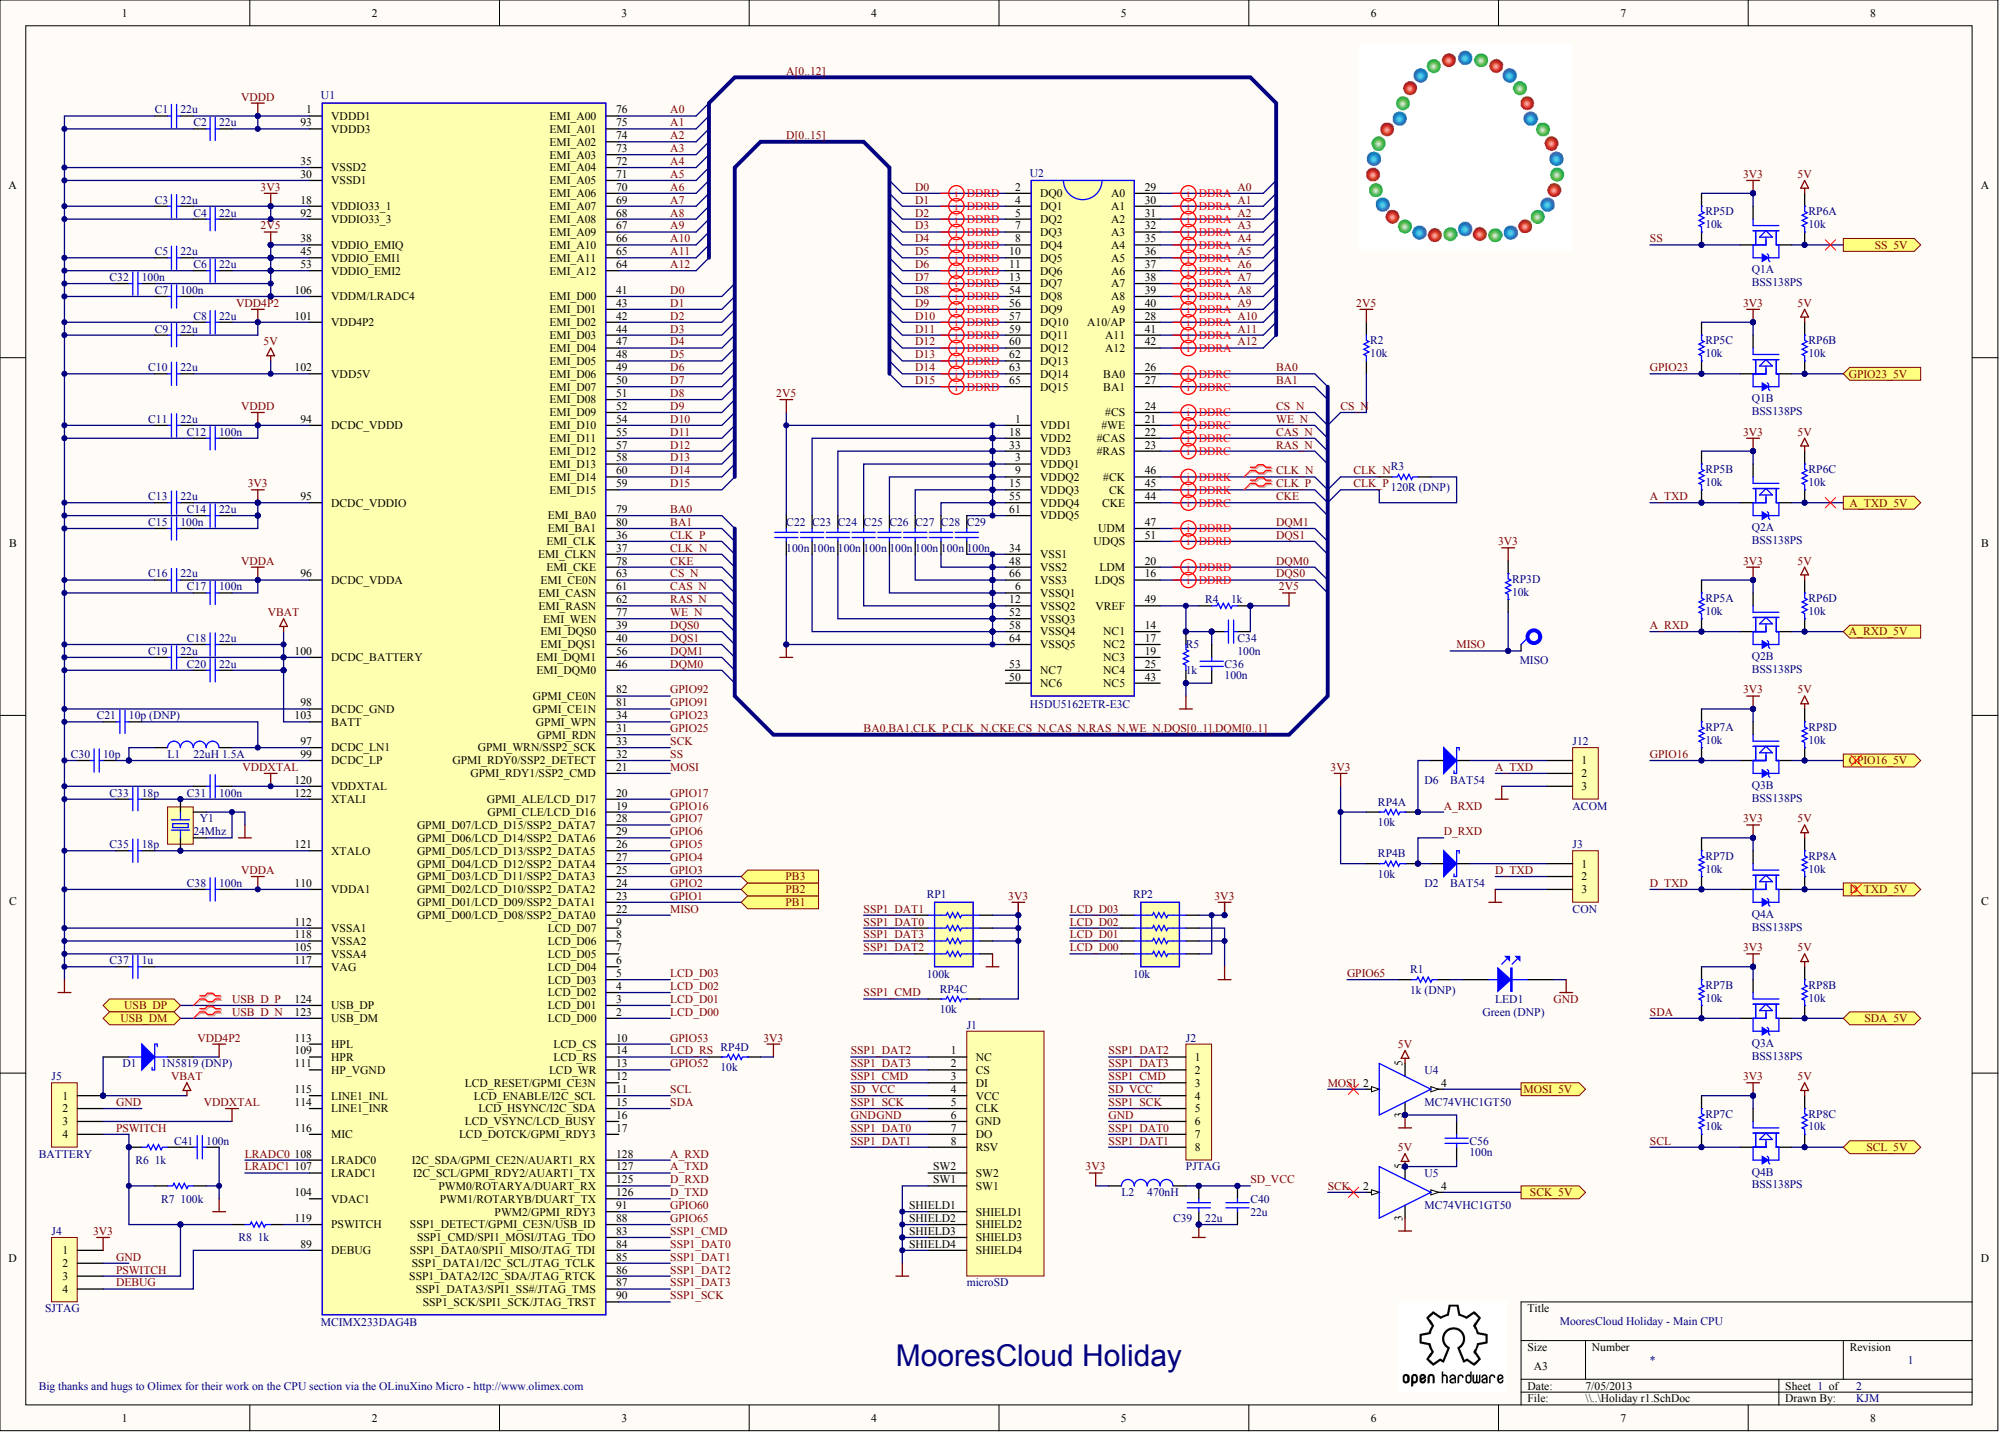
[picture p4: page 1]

i DDRD i DDRD i DDRD i DDRD i DDRD i DDRD i DDRD i DDRD i DDRD i DDRD i DDRD i DDRD i DDRD i DDRD i DDRD

i DDRA i DDRK i DDRK
i DDRA i DDRA i DDRA i DDRA i DDRA i DDRA i DDRA i DDRA i DDRA i DDRA i DDRA i DDRA i DDRD i DDRD i DDRD i DDRD

i DDRC i DDRC i DDRC i DDRC i DDRC i DDRC i DDRC

VDDQ3 15

VSS2 48
VSS3 66

VSSQ2 12

VSSQ4 58

SHIELD1
SHIELD2
SHIELD3

MooresCloud Holiday - Main CPU

Big thanks and hugs to Olimex for their work on the CPU section via the OLinuXino Micro - http://w

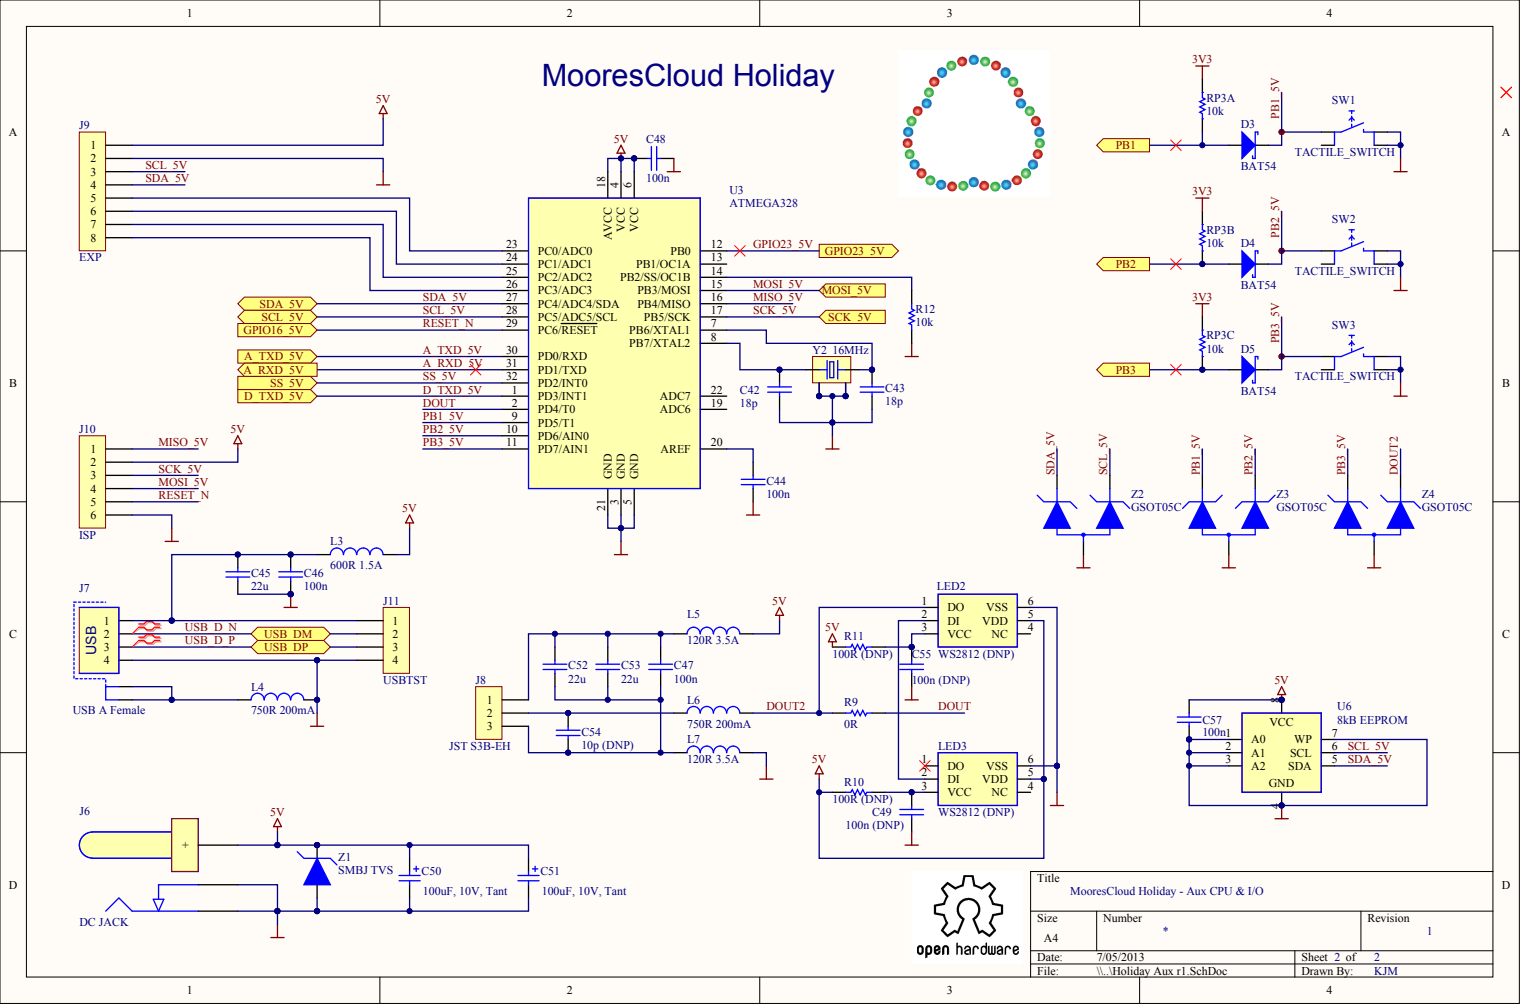
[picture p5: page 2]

PC1/ADC1 24
PC2/ADC2 25
PC3/ADC3 26 | MOSI_5V

PD0/RXD 30 | 8

Y2 16MHz

MooresCloud Holiday - Aux CPU & I/O

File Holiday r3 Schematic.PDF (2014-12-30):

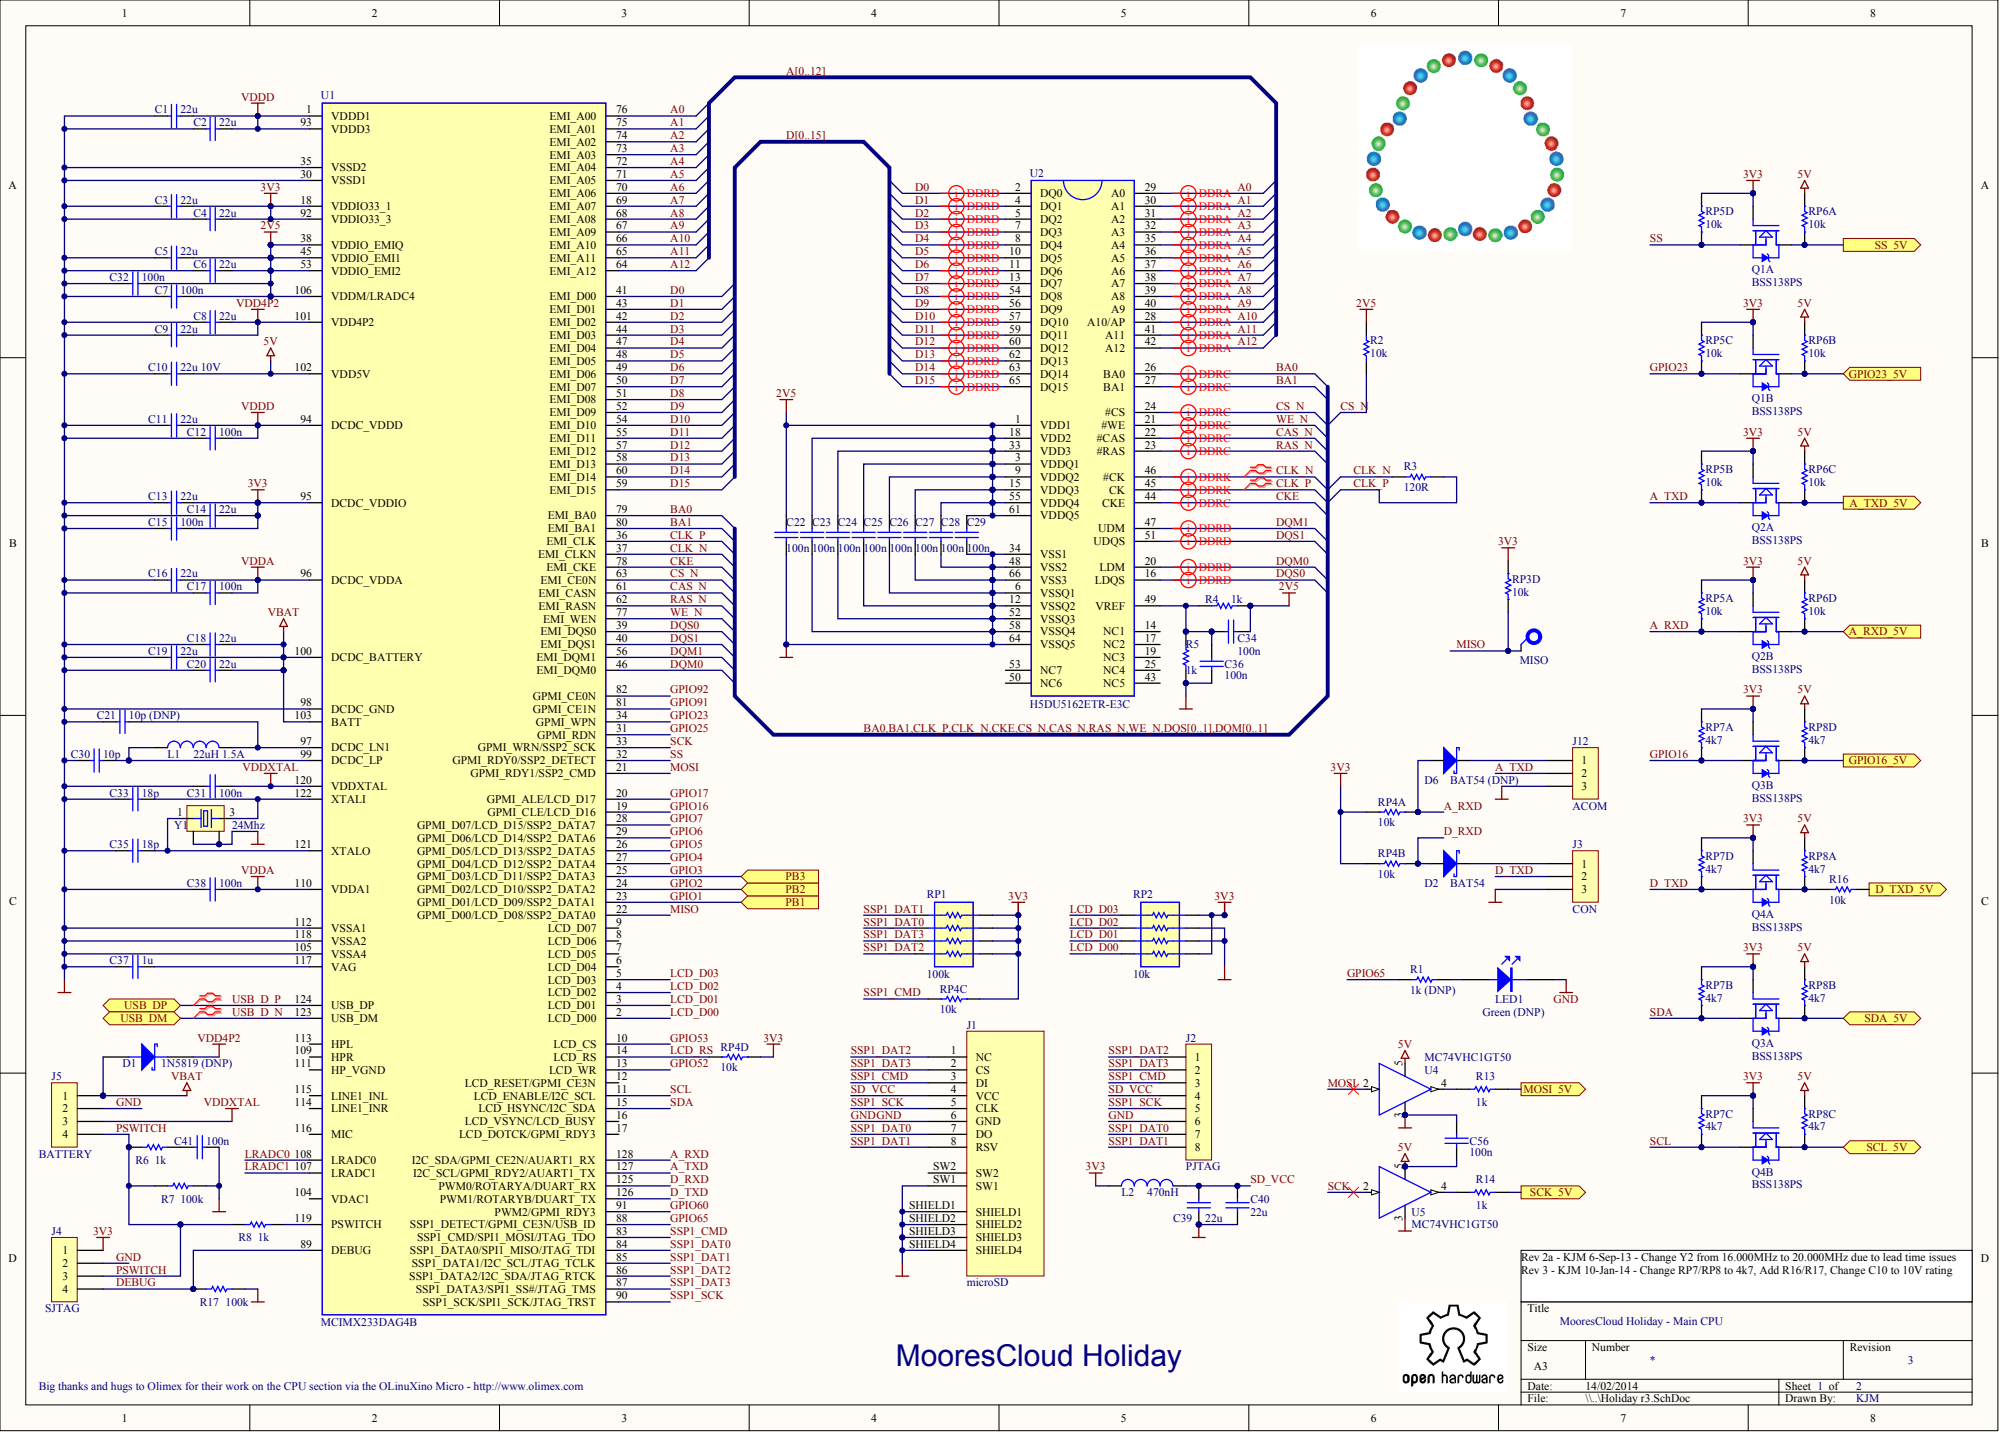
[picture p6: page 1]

i DDRD i DDRD i DDRD i DDRD i DDRD i DDRD i DDRD i DDRD i DDRD i DDRD i DDRD i DDRD i DDRD i DDRD i DDRD

i DDRA i DDRK i DDRK
i DDRA i DDRA i DDRA i DDRA i DDRA i DDRA i DDRA i DDRA i DDRA i DDRA i DDRA i DDRA i DDRD i DDRD i DDRD i DDRD

i DDRC i DDRC i DDRC i DDRC i DDRC i DDRC i DDRC

VDDQ3 15 | CLK_P
VDDQ4 55

VSS2 48
VSS3 66

VSSQ2 12

VSSQ4 58

SHIELD1
SHIELD2
SHIELD3

Rev 2a - KJM 6-Sep-13 - Change Y2 from 16.000MHz to 20.000MHz due to lead time issues
Rev 3 - KJM 10-Jan-14 - Change RP7/RP8 to 4k7, Add R16/R17, Change C10 to 10V rating

MooresCloud Holiday - Main CPU

Big thanks and hugs to Olimex for their work on the CPU section via the OLinuXino Micro - http://w

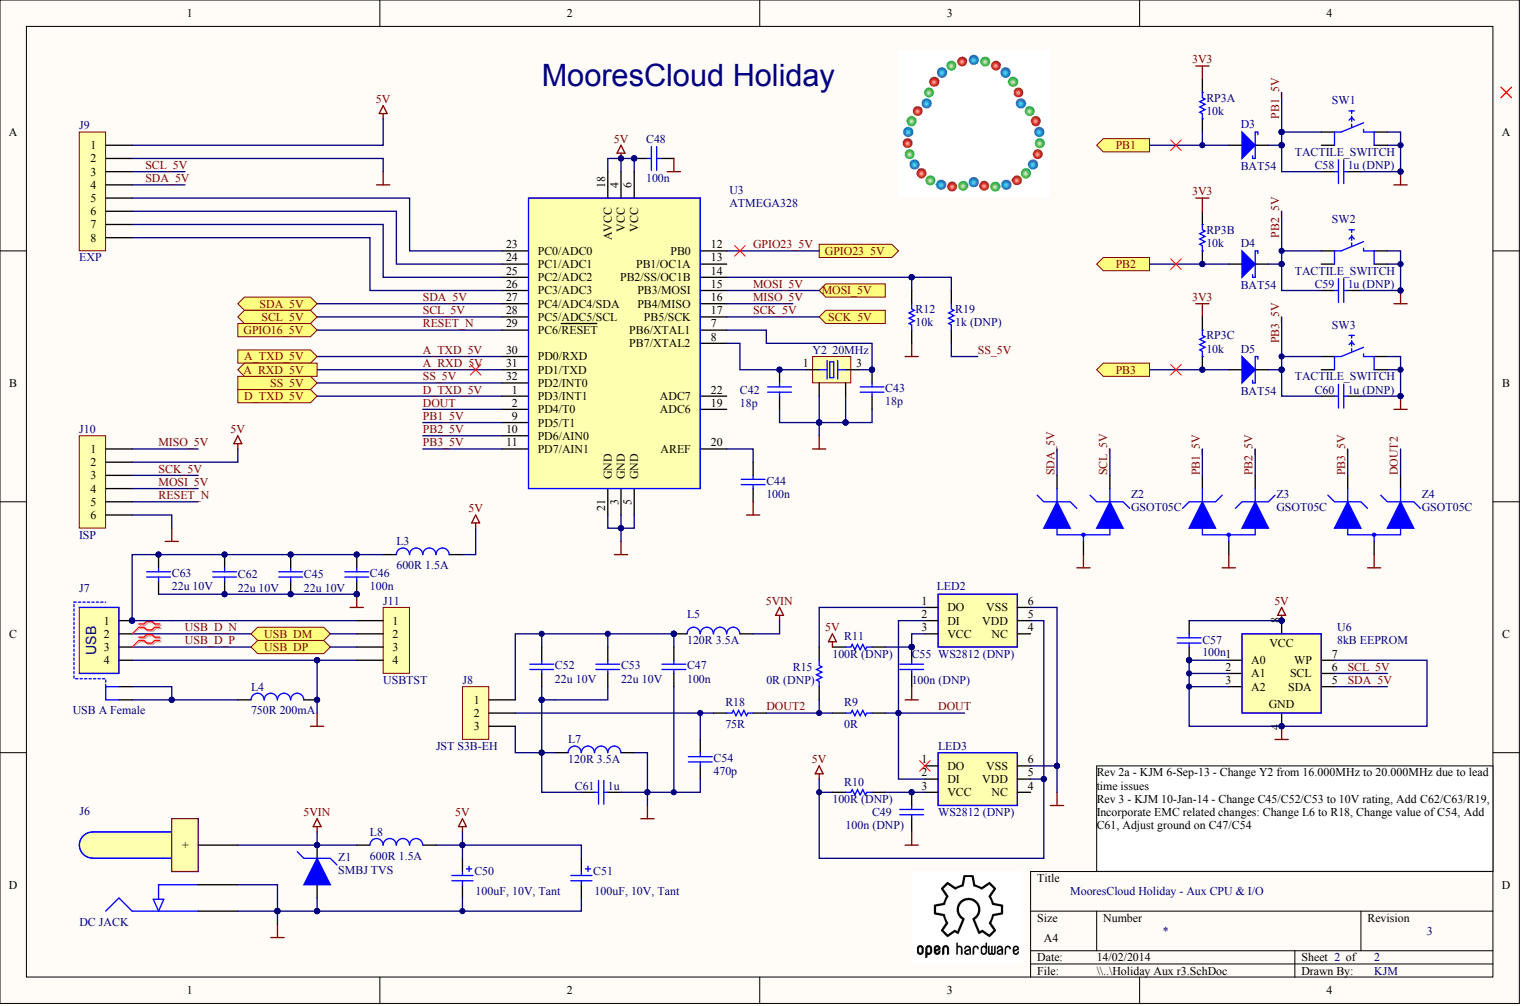
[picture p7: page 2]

PC2/ADC2 25
PC3/ADC3 26 | MOSI_5V

PD0/RXD 30 | 8

Y2 20MHz 1

Rev 2a - KJM 6-Sep-13 - Change Y2 from 16.000MHz to 20.000MHz due to lead
time issues
Rev 3 - KJM 10-Jan-14 - Change C45/C52/C53 to 10V rating, Add C62/C63/R19, Incorporate EMC related changes: Change L6 to R18, Change value of C54, Add

MooresCloud Holiday - Aux CPU & I/O

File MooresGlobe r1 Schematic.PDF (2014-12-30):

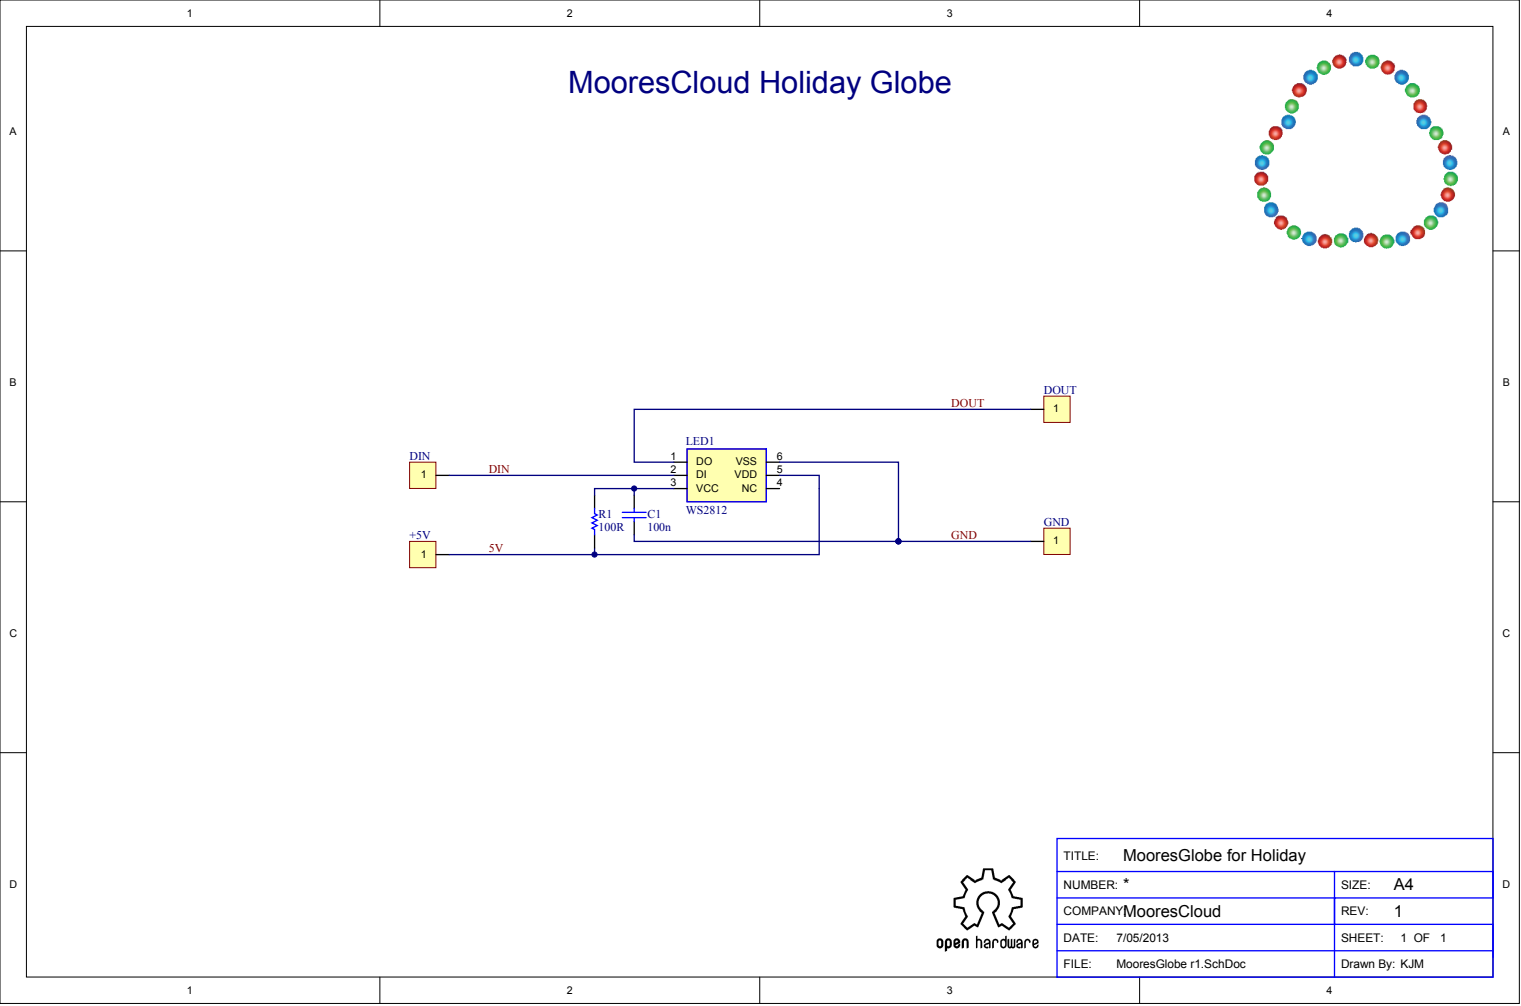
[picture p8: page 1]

NUMBE R : * | SIZE : A4
COMPAN YMooresCloud : | REV : 1

DATE : 7/05/20 1 3 | SHEE T : 1 O F 1

FILE : MooresGlobe r1.SchDoc | Drawn By : KJ M

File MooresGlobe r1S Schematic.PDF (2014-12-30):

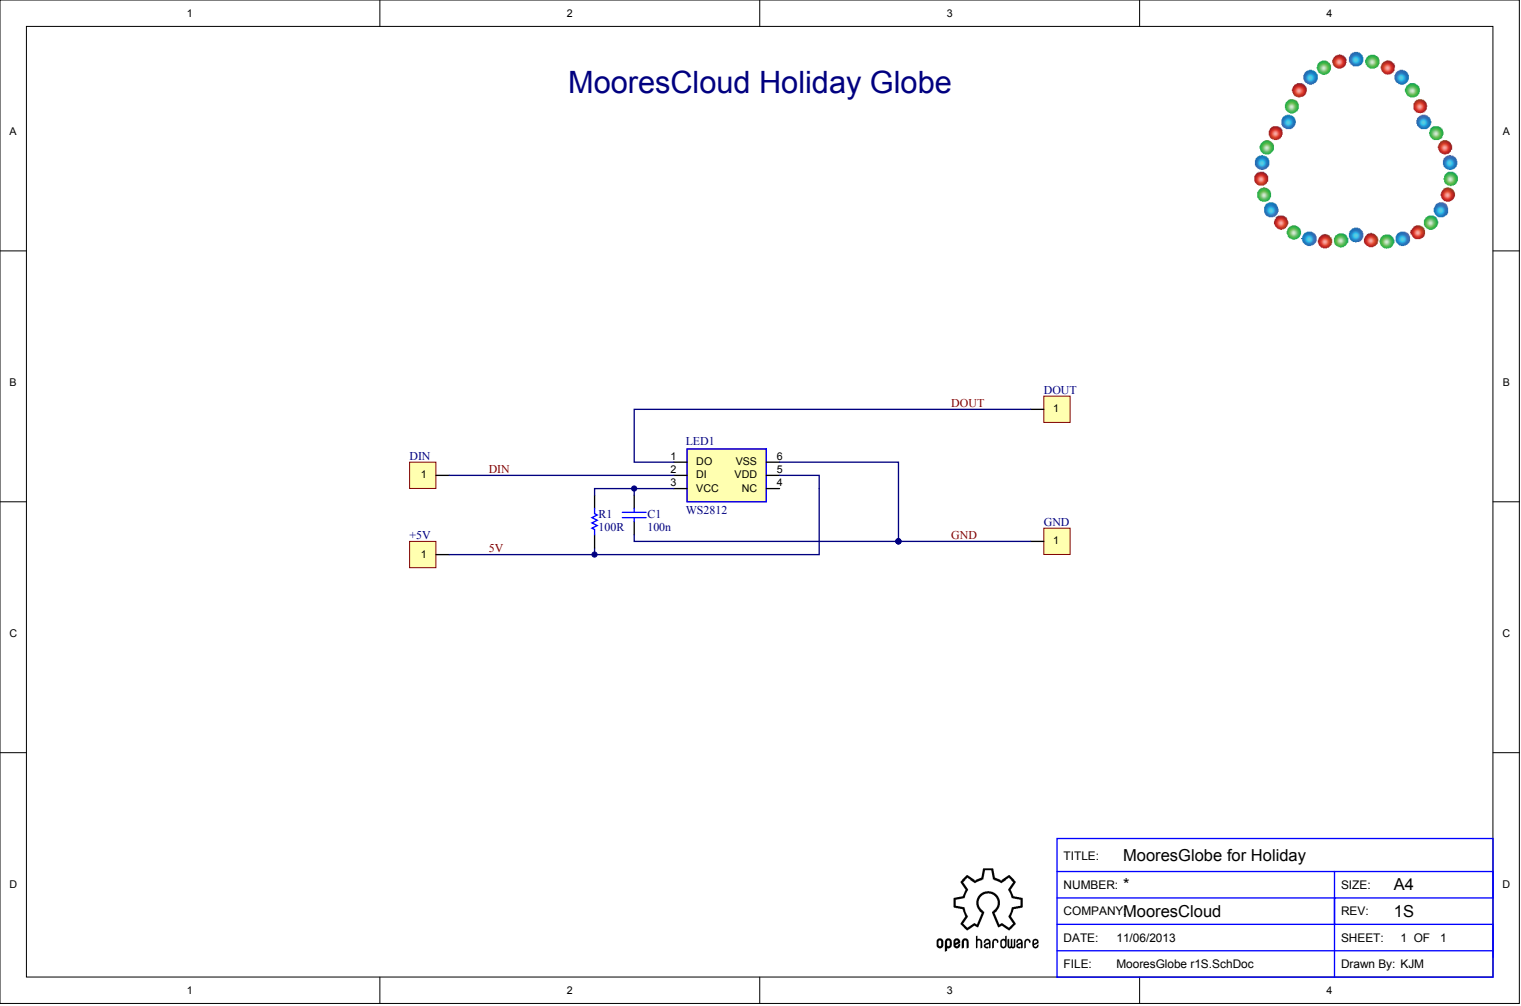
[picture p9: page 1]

NUMBE R : * | SIZE : A4
COMPAN YMooresCloud : | REV : 1S

DATE : 11/06/20 1 3 | SHEE T : 1 O F 1

FILE : MooresGlobe r1S.SchDoc | Drawn By : KJ M

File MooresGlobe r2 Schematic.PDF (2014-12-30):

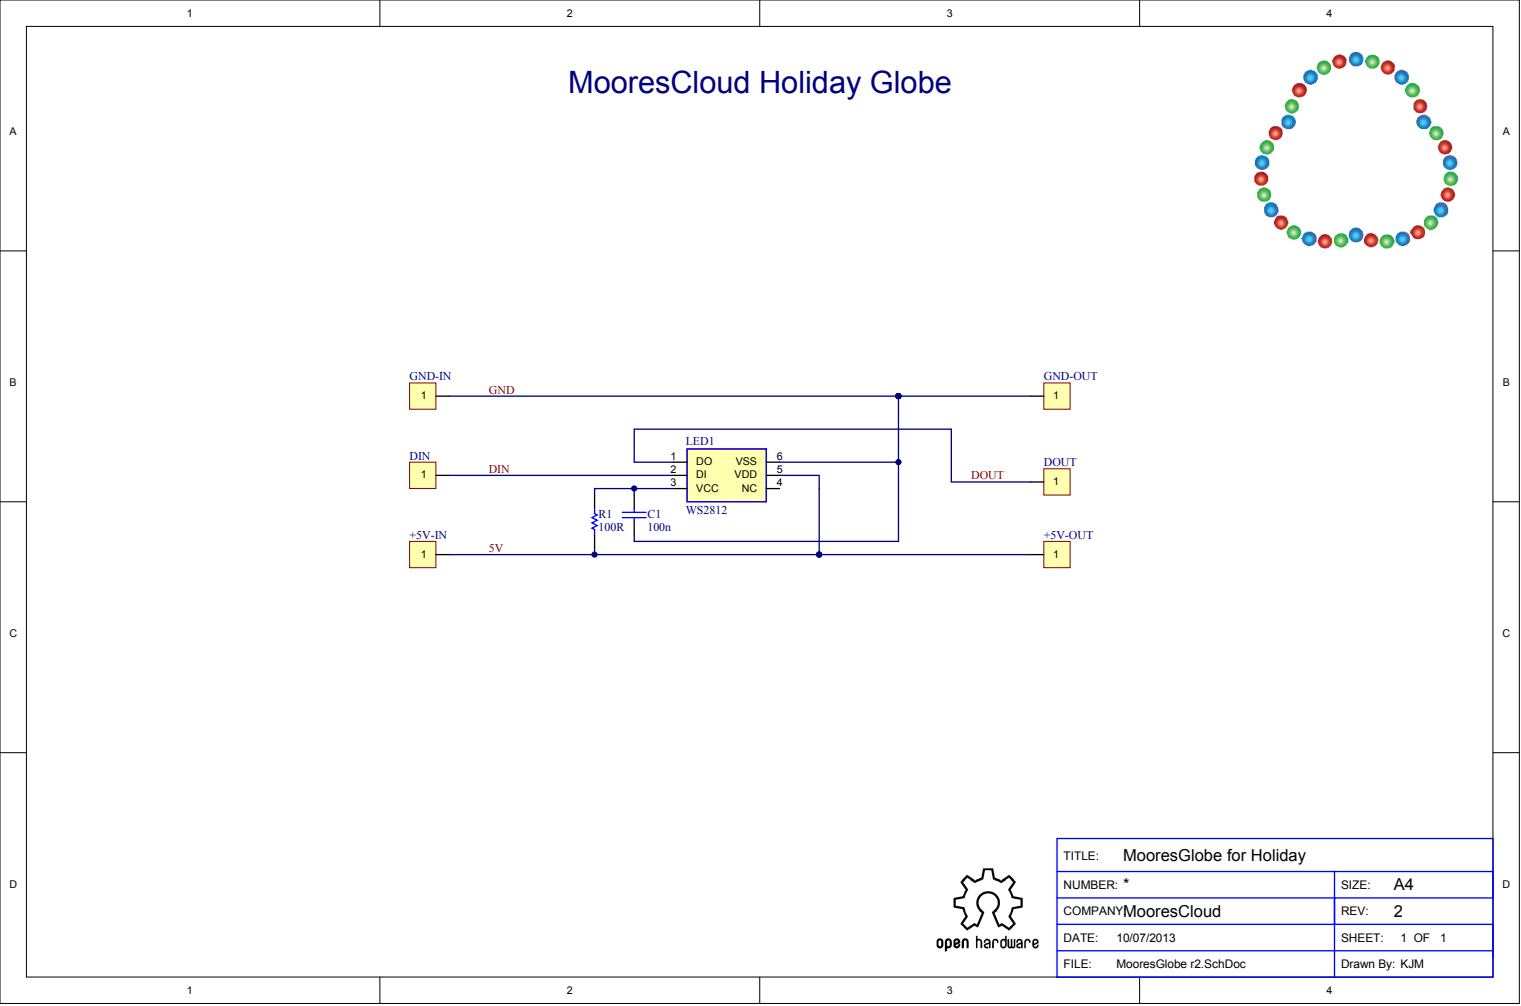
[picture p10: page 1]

NUMBE R : * | SIZE : A4
COMPAN YMooresCloud : | REV : 2

DATE : 10/07/20 1 3 | SHEE T : 1 O F 1

FILE : MooresGlobe r2.SchDoc | Drawn By : KJ M

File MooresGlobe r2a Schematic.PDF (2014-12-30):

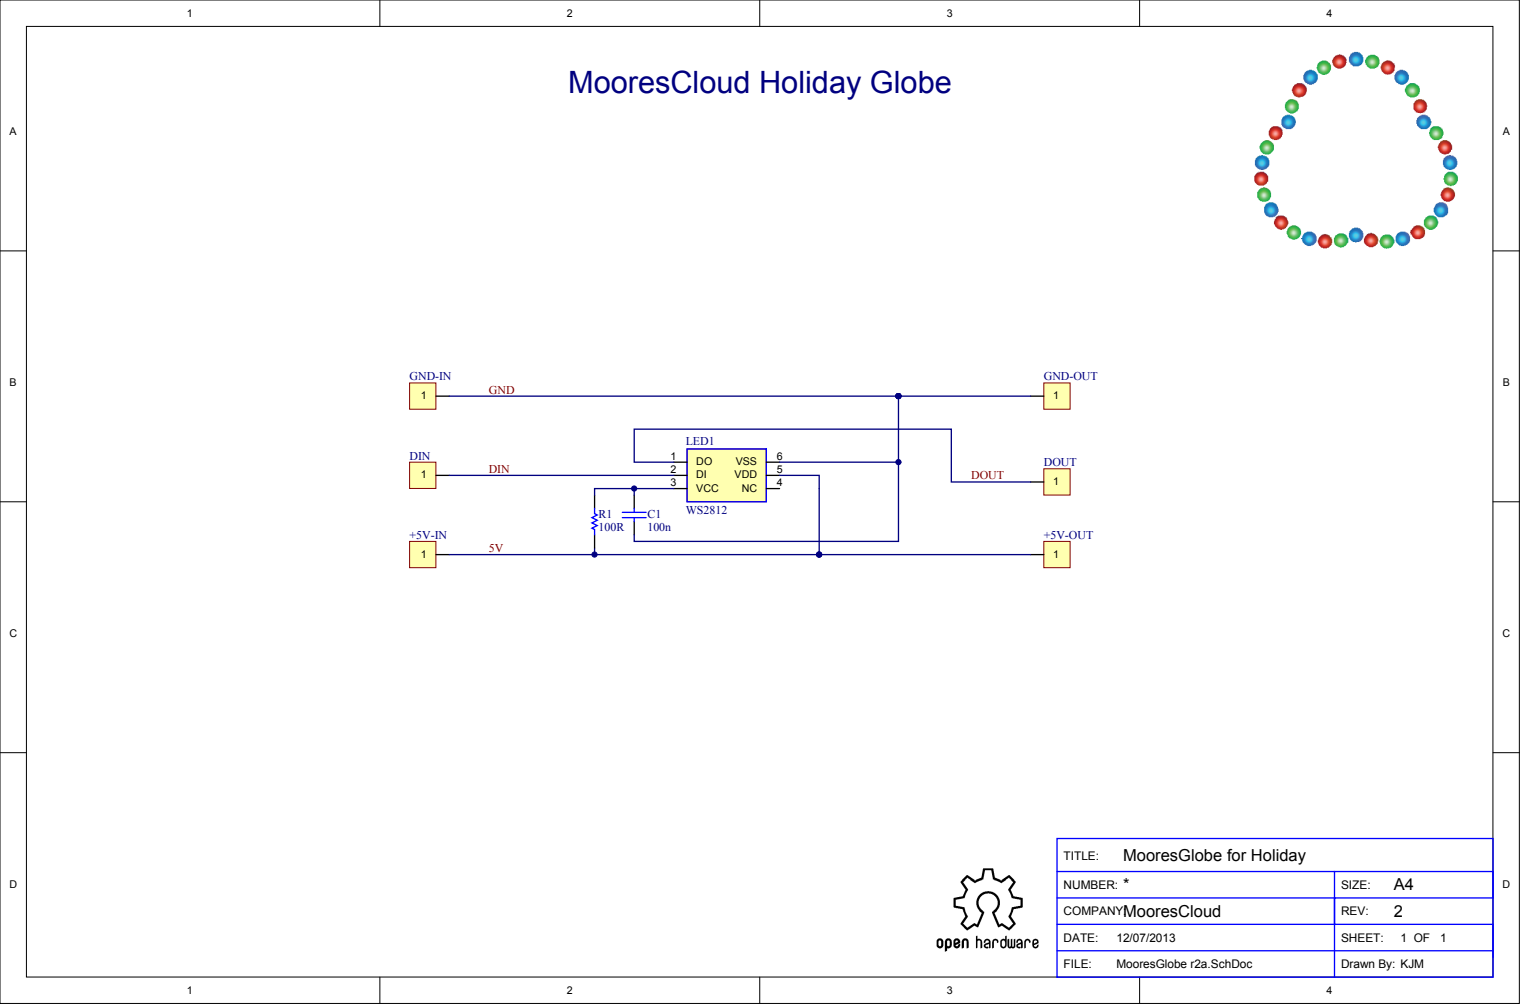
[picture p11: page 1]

NUMBE R : * | SIZE : A4
COMPAN YMooresCloud : | REV : 2

DATE : 12/07/20 1 3 | SHEE T : 1 O F 1

FILE : MooresGlobe r2a.SchDoc | Drawn By : KJ M

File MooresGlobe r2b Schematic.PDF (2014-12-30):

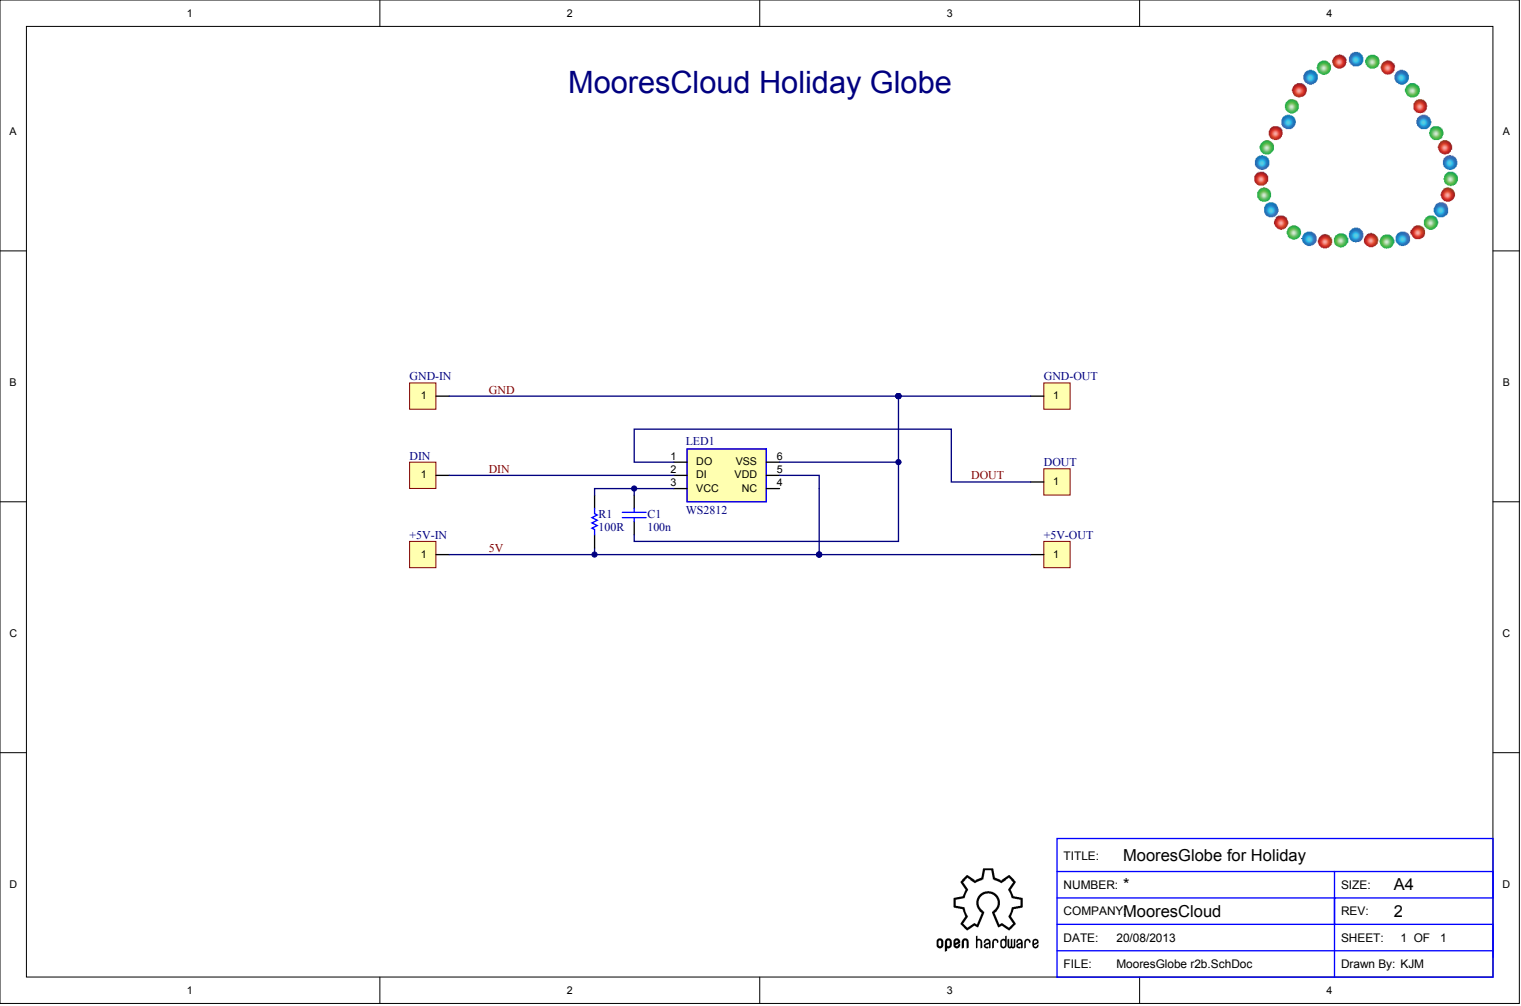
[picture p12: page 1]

NUMBE R : * | SIZE : A4
COMPAN YMooresCloud : | REV : 2

DATE : 20/08/20 1 3 | SHEE T : 1 O F 1

FILE : MooresGlobe r2b.SchDoc | Drawn By : KJ M

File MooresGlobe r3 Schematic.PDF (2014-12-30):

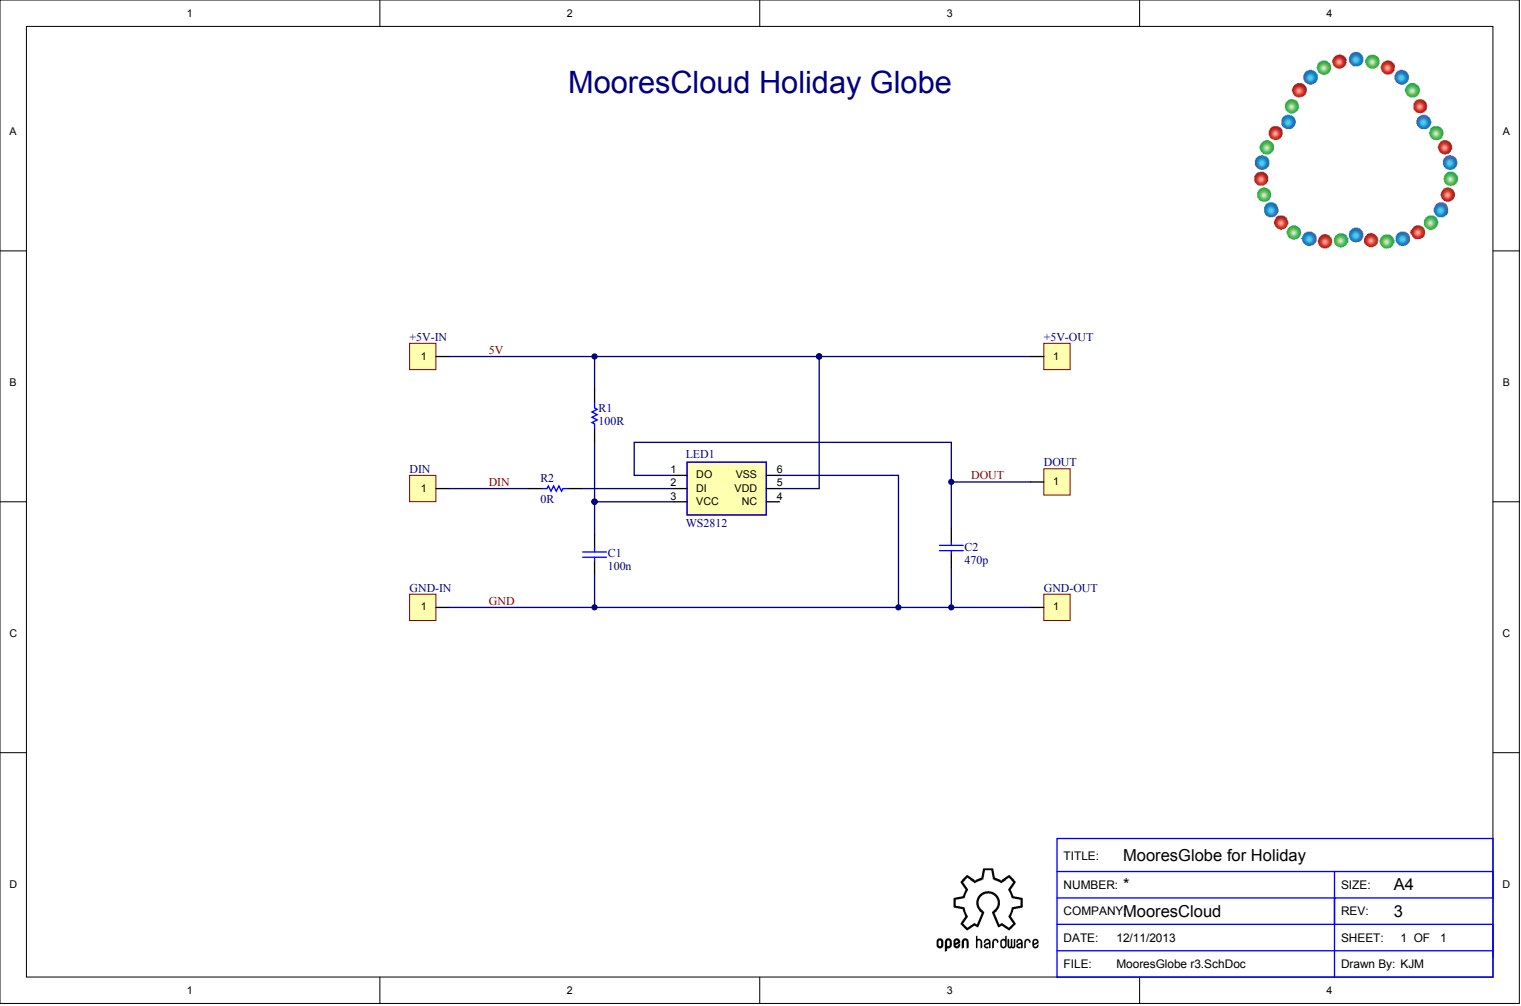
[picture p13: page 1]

NUMBE R : * | SIZE : A4
COMPAN YMooresCloud : | REV : 3

DATE : 12/11/20 1 3 | SHEE T : 1 O F 1

FILE : MooresGlobe r3.SchDoc | Drawn By : KJ M

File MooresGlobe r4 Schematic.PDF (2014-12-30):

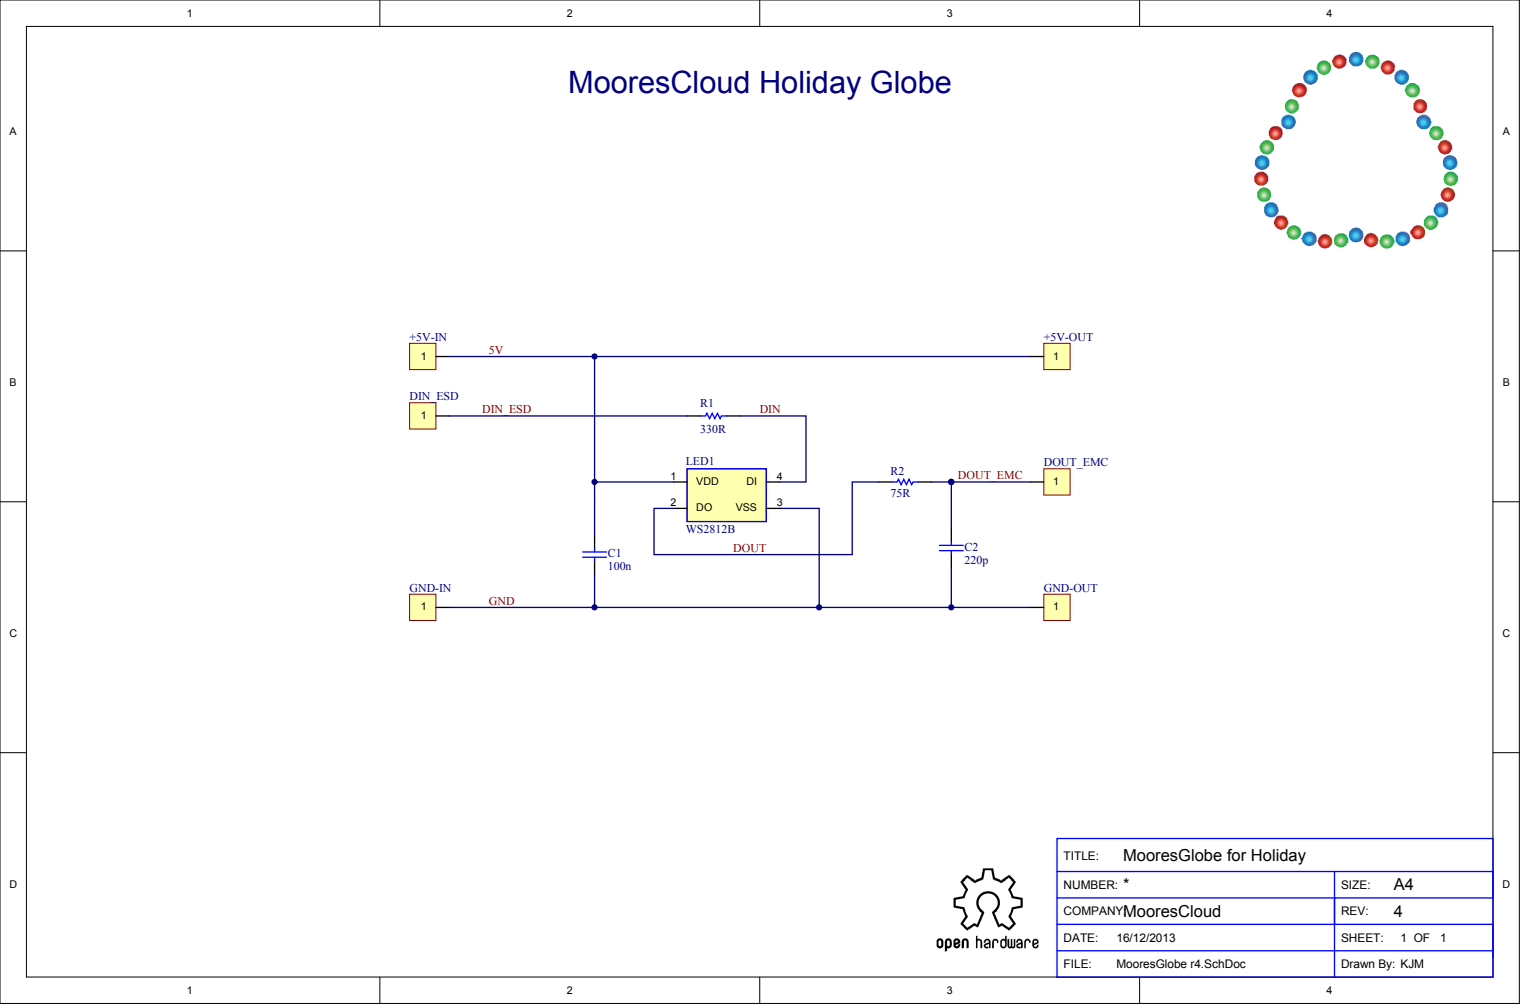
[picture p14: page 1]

NUMBER: * | SIZE: A4
COMPANYMooresCloud : | REV: 4

DATE: 16/12/2013 | SHEET: 1 OF 1

FILE: MooresGlobe r4.SchDoc | Drawn By: KJM

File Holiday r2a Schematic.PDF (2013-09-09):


i DDRD i DDRD i DDRD i DDRD i DDRD i DDRD i DDRD i DDRD i DDRD i DDRD i DDRD i DDRD i DDRD i DDRD i DDRD

i DDRA i DDRK i DDRK
i DDRA i DDRA i DDRA i DDRA i DDRA i DDRA i DDRA i DDRA i DDRA i DDRA i DDRA i DDRA i DDRD i DDRD i DDRD i DDRD

i DDRC i DDRC i DDRC i DDRC i DDRC i DDRC i DDRC

VDDQ3 15 | CLK_P
VDDQ4 55

VSS2 48
VSS3 66

VSSQ2 12

VSSQ4 58

SHIELD1
SHIELD2
SHIELD3

Rev 2a - KJM 6-Sep-13 - Change Y2 from 16.000MHz to 20.000MHz due to lead time issues

MooresCloud Holiday - Main CPU

Big thanks and hugs to Olimex for their work on the CPU section via the OLinuXino Micro - http://w


PC2/ADC2 25
PC3/ADC3 26 | MOSI_5V

PD0/RXD 30 | 8

Y2 20MHz 1

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

MooresCloud Holiday - Aux CPU & I/O






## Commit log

2013-07-05 Initial commit for Holiday r2 hardware files
    [Holiday r2 BOM (Standard).xls, Holiday r2.PcbDoc, Holiday r2.SchDoc]
2013-09-09 Revision 2a
    [Holiday r2a BOM (Standard).xls]
2014-12-30 Add more revisions & Altium source files
    [Holiday r1 BOM (Standard).xls, Holiday r2.PcbDoc, Holiday r2.SchDoc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]
